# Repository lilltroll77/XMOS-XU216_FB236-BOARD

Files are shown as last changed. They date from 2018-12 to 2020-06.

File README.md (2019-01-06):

# XMOS-XU216_FB236-BOARD
### XMOS XU216-FB236 BOARD made in KiCad
**Current status: In DEVELOPMENT**

A 100 x 100 mm 4 layer PCB based on the XMOS XU216 FB236 chip. PCB can be cascaded during development with full JTAG support, and then be used as a galvanic isolated network without JTAG.\
[Schematic as pdf](https://github.com/lilltroll77/XMOS-XU216_FB236-BOARD/blob/master/XMOS_XUF216_FB236.pdf)

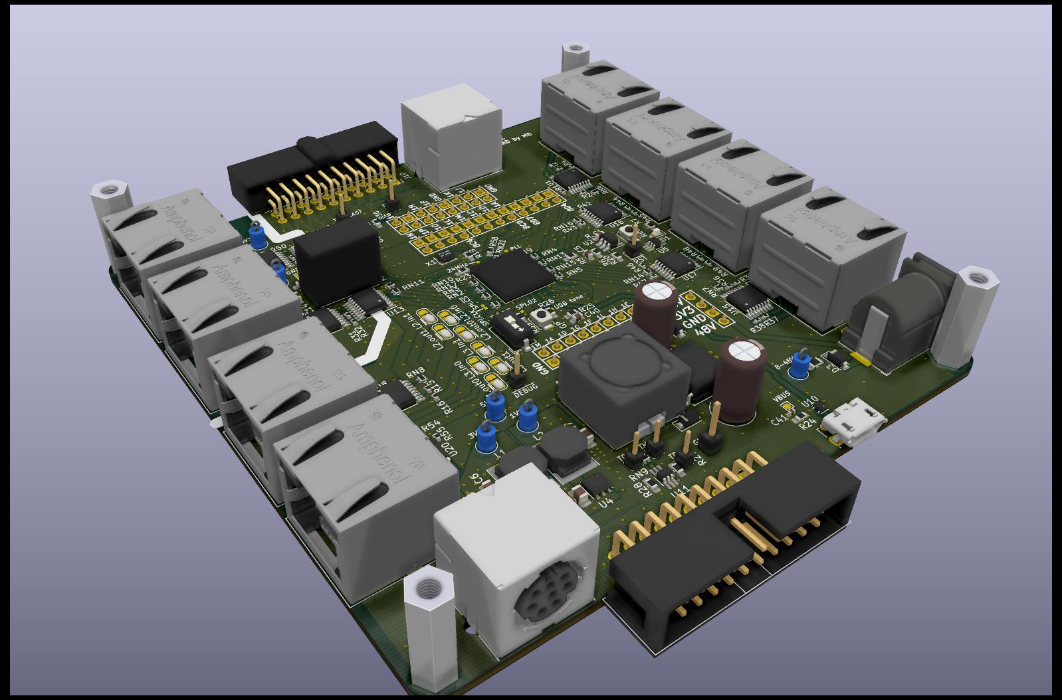
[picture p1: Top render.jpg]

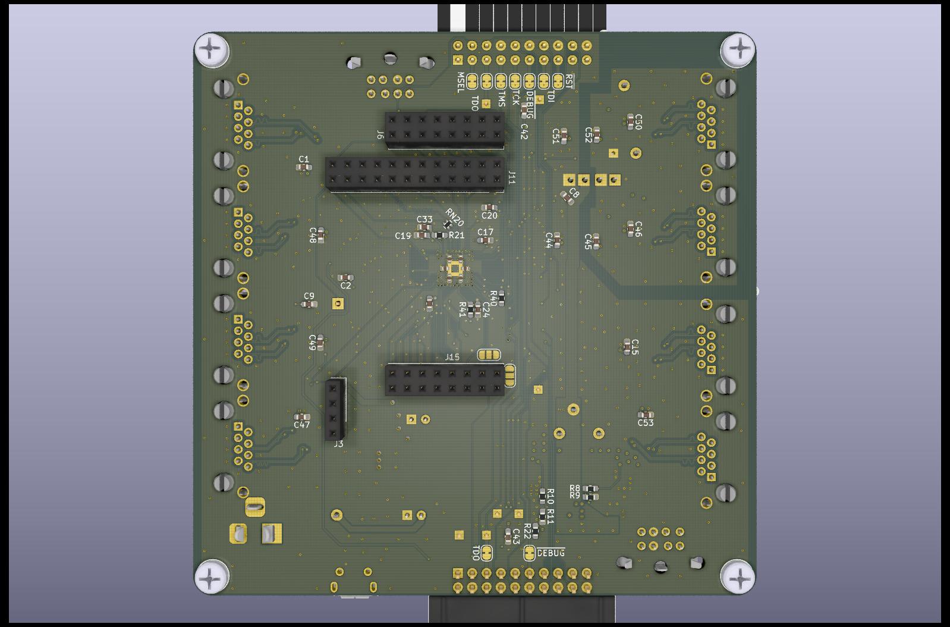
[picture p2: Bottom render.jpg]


The wrl file is a Virtual reality modeling language file of the board with components. 
It can be opened in [FreeCad](https://www.freecadweb.org/) with hardware acceleration. 
Software rendereing is not recommended for realtime view.
The parts for the PCB are stored in the shapes3D folder.

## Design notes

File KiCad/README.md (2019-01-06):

The library for the board should be included in the file XMOS_XUF216_FB236-cache.lib\
To view all 3D parts, you might need to add an alias in the KiCad "3D Search Path Configuration" window\
Alias = vrml\
Path = The path to the shapes3D folder on your local machine. (After you have cloned this project)

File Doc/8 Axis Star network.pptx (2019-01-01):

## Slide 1

Star network + JTAG line.
Compiler can create
the routing table for 1-9 PCBs.
Hub can be flashed, cards separated,
without any change to the code.
Isolation works when separated.

0

| JTAG | XL7
XL0 | XUF216 | XL6
XL1 | USB | XL5
| JTAG | XL4

| JTAG | XL7
XL0 | XUF216 | XL6
XL1 | USB | XL5
| JTAG | XL4

IDC

1

2

| JTAG | XL7
XL0 | XUF216 | XL6
XL1 | USB | XL5
| JTAG | XL4

IDC

COLOR = ACTIVATED

Tested with 9 PCBs in a star + XTAG line.
Full JTAG debug.
Realtime Stdout over UART.
Compiles and runs in the simulator.

3

| JTAG | XL7
XL0 | XUF216 | XL6
XL1 | USB | XL5
| JTAG | XL4

IDC

IDC

4

| JTAG | XL7
XL0 | XUF216 | XL6
XL1 | USB | XL5
| JTAG | XL4

5

| JTAG | XL7
XL0 | XUF216 | XL6
XL1 | USB | XL5
| JTAG | XL4

IDC

| JTAG | XL7
XL0 | XUF216 | XL6
XL1 | | XL5
| JTAG | XL4

IDC

6

PC

0

1

3

FLASH XL3 | JTAG | XL7
XL0 | XUF216 | XL6
XL1 | | XL5
USB XL2 | UART JTAG | XL4

XTAG UART

IDC

6

7 (not shown)

5

2

IDC

HUB

Boots over JTAG or from Flash

4

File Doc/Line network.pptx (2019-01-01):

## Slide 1

Simple line network. Compiler can
create the routing table for any length.
The Xlink bandwidth must be shared
between the boards.
Not suitable for robotics.

| XL3 JTAG | XL7
XL0 | XUF216 | XL6
XL1 | USB | XL5
| XL2 JTAG | XL4

COLOR = ACTIVATED

| XL3 JTAG | XL7
XL0 | XUF216 | XL6
XL1 | USB | XL5
| XL2 JTAG | XL4

IDC

Tested with 8 PCBs in a line + XTAG.
Full JTAG debug.
Compiles and runs in the simulator.

| XL3 JTAG | XL7
XL0 | XUF216 | XL6
XL1 | USB | XL5
| XL2 JTAG | XL4

IDC

| XL3 JTAG | XL7
XL0 | XUF216 | XL6
XL1 | | XL5
| XL2 JTAG | XL4

IDC

FLASH | XL3 JTAG | XL7
XL0 | XUF216 | XL6
XL1 | | XL5
USB | XL2 JTAG | XL4

XTAG

IDC

PC

IDC

Boots over JTAG or Flash

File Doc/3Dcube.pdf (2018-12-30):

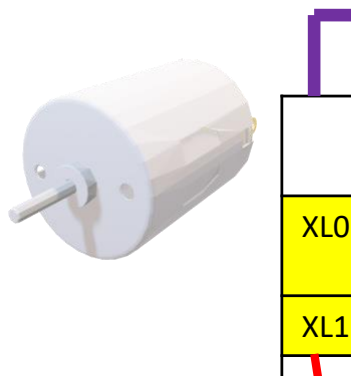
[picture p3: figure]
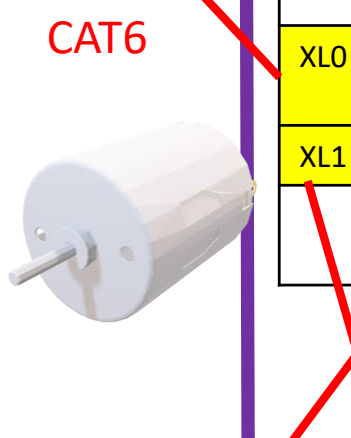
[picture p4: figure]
CAT6
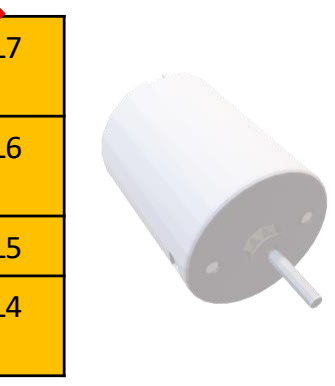
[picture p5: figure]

FLASH | XL3 JTAG | XL7
XL0 | XUF 216 IO | XL6

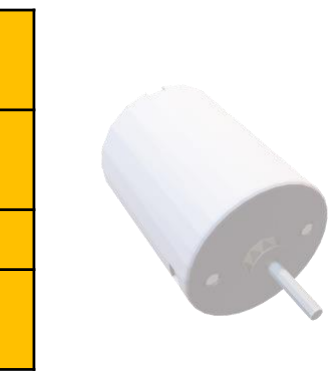
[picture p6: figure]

XL1 | | XL5
USB | XL2 JTAG | XL4

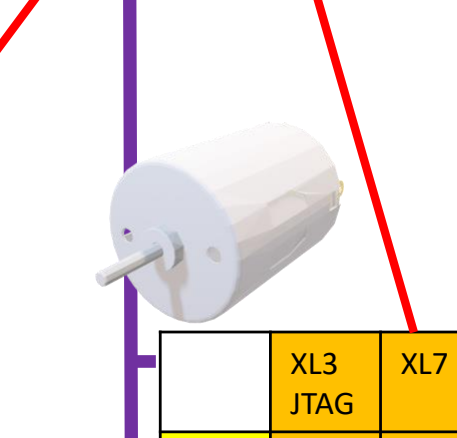
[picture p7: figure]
XL3 JTAG

XL0 | XUF 216 IO | XL6
XL1 | | XL5
| XL2 JTAG | XL4

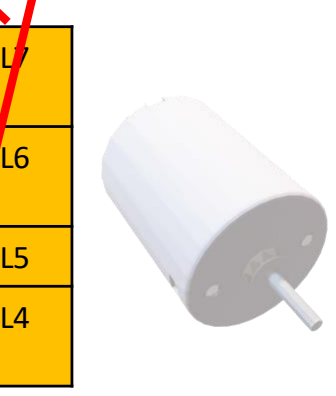
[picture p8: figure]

XL3
JTAG

XL7

XL0 | XUF
| 216 | XL6
XL1 | IO | XL5
| XL2 JTAG | XL4

## IDC

## IDC

## IDC

PC

## Isolated 3D cube network

## PSU

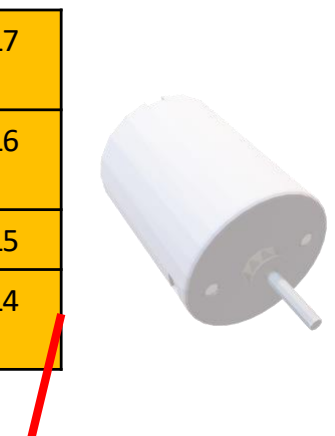
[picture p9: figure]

XL3 JTAG | XL7
XL0 | XUF 216 IO | XL6
XL1 | | XL5
| XL2 JTAG | XL4
| XL3 JTAG | XL7
XL0 | XUF 216 IO | XL6
XL1 | | XL5
| XL2 JTAG | XL4

## IDC

## IDC

XL3
JTAG

XL7

XL0 | XUF
| 216 | XL6
XL1 | IO | XL5
| XL2 JTAG | XL4
| XL3 JTAG | XL7
XL0 | XUF 216 IO | XL6
XL1 | | XL5
| XL2 JTAG | XL4

## IDC

## IDC

| XL3 JTAG | XL7
XL0 | XUF 216 IO | XL6
XL1 | | XL5
| XL2 JTAG | XL4

## IDC

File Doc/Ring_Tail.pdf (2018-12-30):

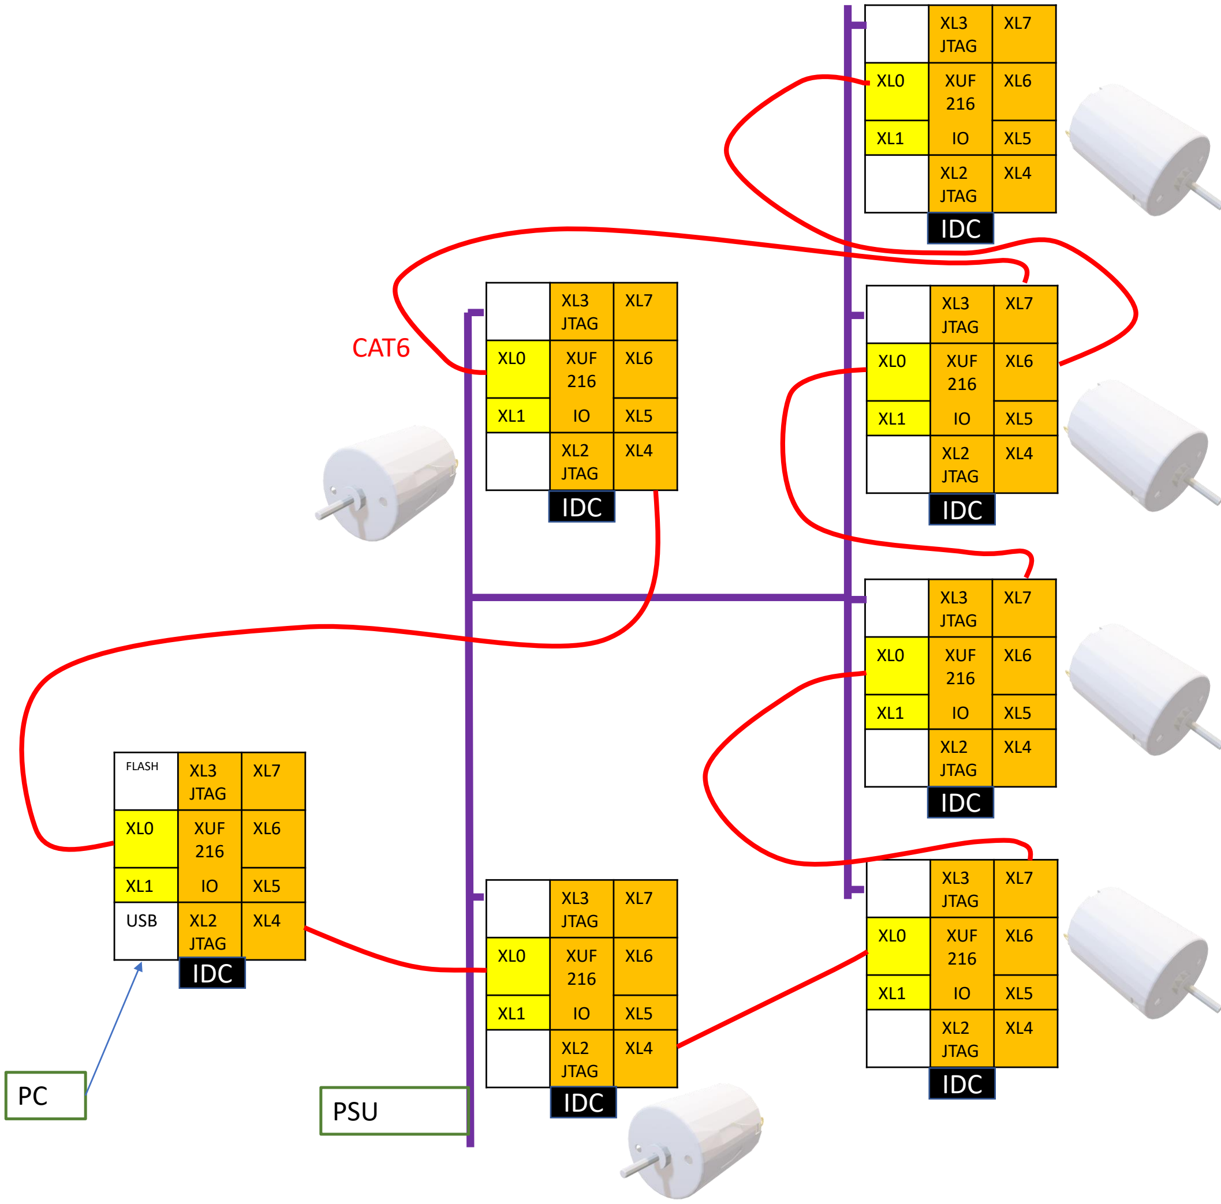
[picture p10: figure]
FLASH; XL3 JTAG; XUF 216 IO; USB; XL2 JTAG; XUF; IDC; CAT6; PSU

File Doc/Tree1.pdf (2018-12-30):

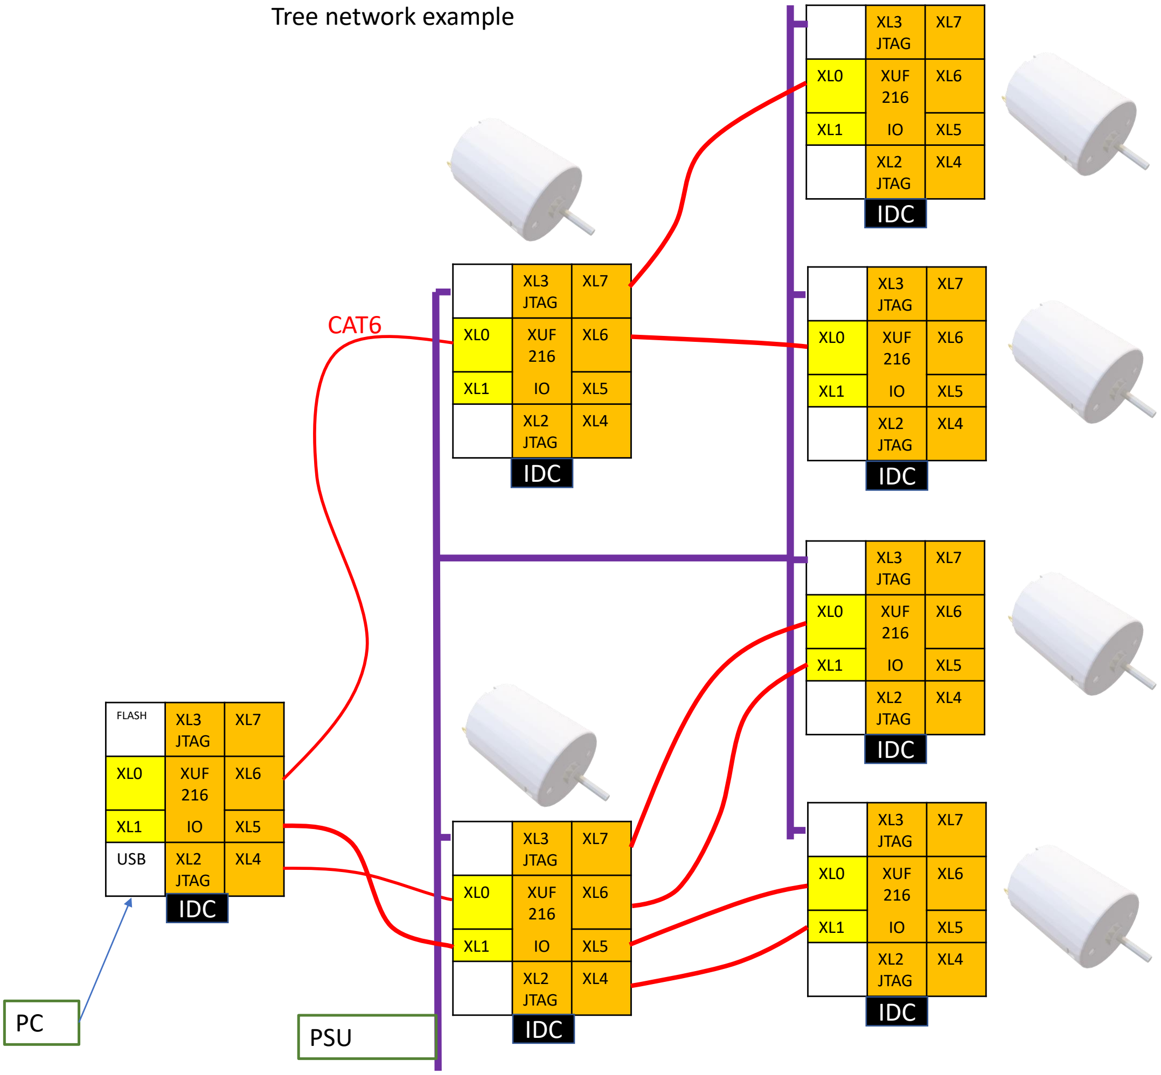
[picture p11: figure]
FLASH; XL3 JTAG; XUF 216 IO; USB; XL2 JTAG; XUF; IDC; CAT6; PSU; Tree network example

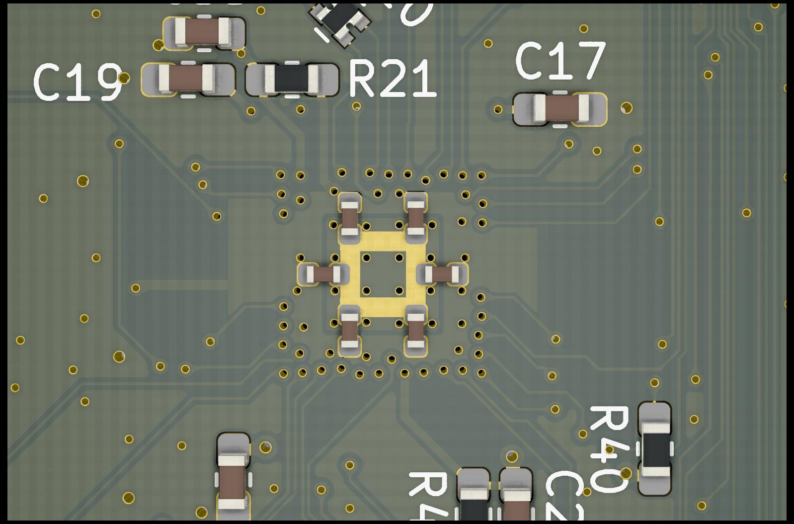
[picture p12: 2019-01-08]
1V0 0402Caps.jpg

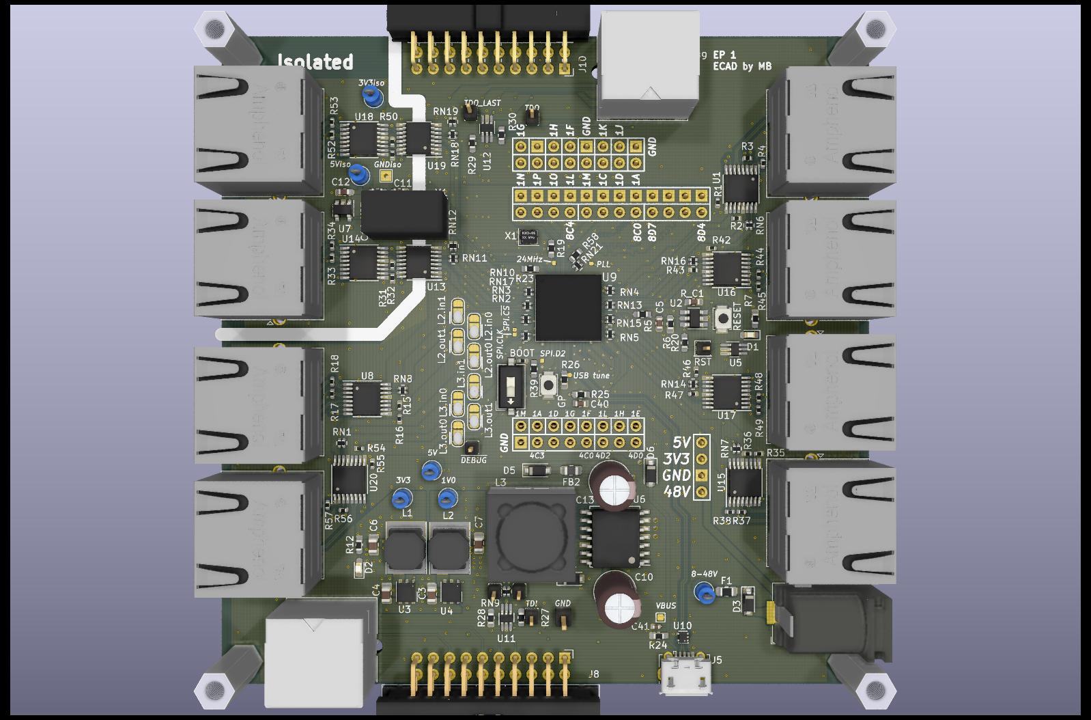
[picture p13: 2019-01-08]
Top render2.jpg

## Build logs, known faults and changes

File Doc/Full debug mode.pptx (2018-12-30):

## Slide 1

Advanced debugging during development

| XL3 JTAG | XL7
XL0 | XUF216 | XL6
XL1 | USB | XL5
| XL2 JTAG | XL4

| XL3 JTAG | XL7
XL0 | XUF216 | XL6
XL1 | USB | XL5
| XL2 JTAG | XL4

IDC

| XL3 JTAG | XL7
XL0 | XUF216 | XL6
XL1 | USB | XL5
| XL2 JTAG | XL4

IDC

| XL3 JTAG | XL7
XL0 | XUF216 | XL6
XL1 | USB | XL5
| XL2 JTAG | XL4

FLASH | XL3 JTAG | XL7
XL0 | XUF216 | XL6
XL1 | | XL5
USB | XL2 JTAG | XL4

XTAG

IDC

IDC

PC

IDC

Boots over JTAG

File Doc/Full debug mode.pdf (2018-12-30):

# XTAG

FLASH | XL3 JTAG | XL7
XL0 | XUF 216 | XL6
XL1 | | XL5
USB | XL2 JTAG | XL4
| XL3 JTAG | XL7
XL0 | XUF 216 USB | XL6
XL1 | | XL5
| XL2 JTAG | XL4
| XL3 JTAG | XL7
XL0 | XUF 216 USB | XL6
XL1 | | XL5
| XL2 JTAG | XL4
| XL3 JTAG | XL7
XL0 | XUF 216 USB | XL6
XL1 | | XL5
| XL2 JTAG | XL4
| XL3 JTAG | XL7
XL0 | XUF 216 USB | XL6
XL1 | | XL5
| XL2 JTAG | XL4

## IDC

## IDC

## IDC

## IDC

## IDC

PC

## Advanced debugging during development

## Boots over JTAG

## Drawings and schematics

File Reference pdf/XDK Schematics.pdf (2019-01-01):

## UART_TXD UART_RXD

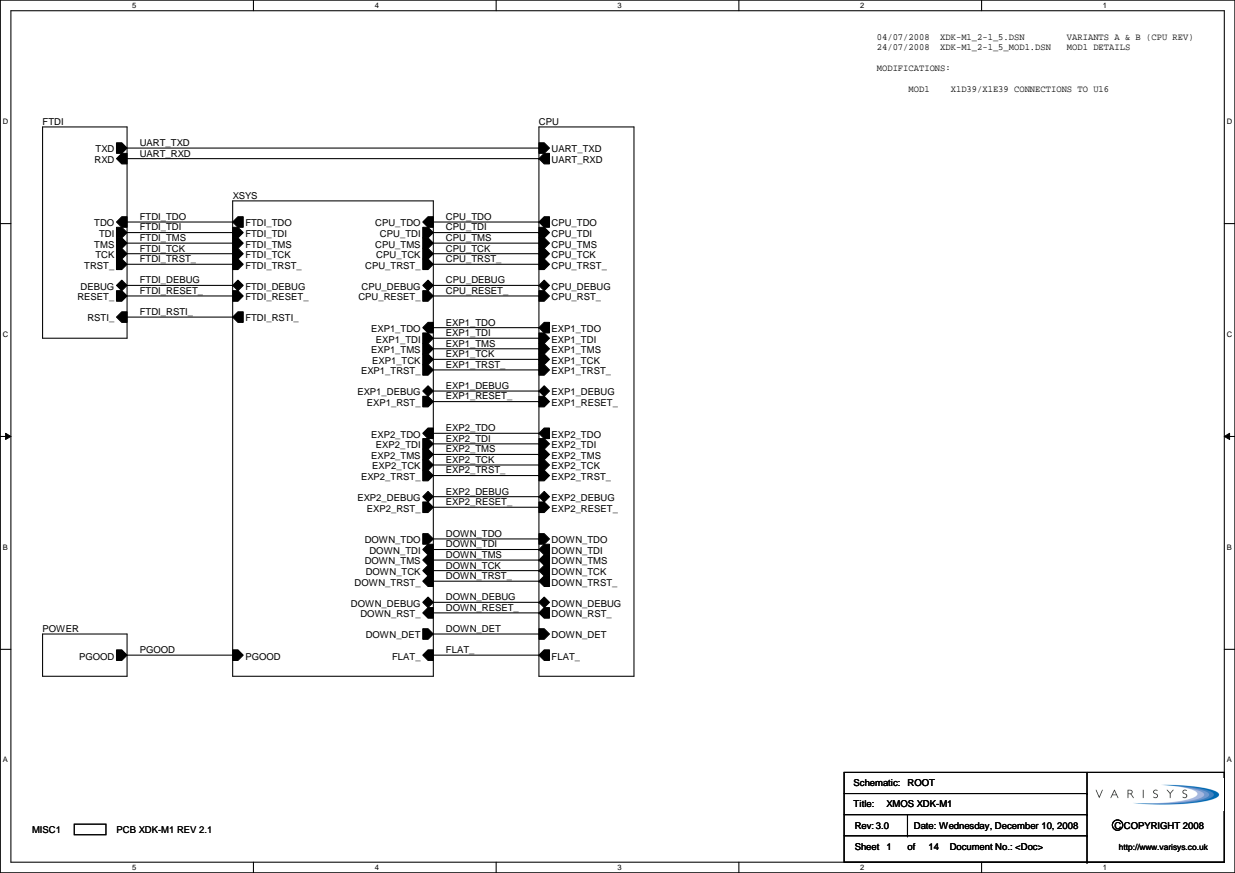
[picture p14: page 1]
CPU_TDO CPU_TDI; DOWN_DET; FLAT_; EXP1_TCK EXP1_TRST_; EXP1_TMS; EXP1_DEBUG EXP1_RESET_; EXP1_TDI; EXP2_TDO; EXP2_TCK EXP2_TRST_; EXP2_TMS; EXP2_DEBUG EXP2_RESET_; EXP2_TDI; DOWN_TDO; DOWN_TCK DOWN_TRST_; DOWN_TMS; DOWN_DEBUG DOWN_RESET_; DOWN_TDI; FTDI_TDO FTDI_TDI; PGOOD; Title:; Document No.:; Rev:; Date:; Sheet; C COPYRIGHT 2008; Schematic:; <Doc>; http://www.varisys.co.uk; XMOS XDK-M1; Wednesday, December 10, 2008; ROOT; 04/07/2008 XDK-M1_2-1_5.DSN; VARIANTS A & B (CPU REV); MOD1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

FTDI_TMS | CPU_TMS
FTDI_TCK | CPU_TCK
FTDI_TRST_ | CPU_TRST_

FTDI_DEBUG | CPU_DEBUG
FTDI_RESET_ | CPU_RESET_

FTDI_RSTI_ | EXP1_TDO

## SPARE

SPARE M22 | SPARE | AD16 SPARE | AD14 SPARE | AD13 SPARE | AD12 SPARE | AD11 SPARE | AD9 SPARE | AC22 SPARE | AC14 SPARE | AC13 SPARE | AC12 SPARE | AC11 SPARE | AC3 SPARE | AB24 SPARE | AB16 SPARE | AB15 SPARE | AB13 SPARE | AB12 SPARE | AB10 SPARE | AB9 SPARE | AB1 SPARE | AA15 SPARE | AA14 SPARE | AA13 SPARE | AA12 SPARE | AA11 SPARE | AA10 SPARE | T23 SPARE | T2 SPARE | P22 SPARE | P2 SPARE | P1 SPARE | N22 SPARE | N21 SPARE | N4 SPARE | N3 SPARE | N2 SPARE | N1

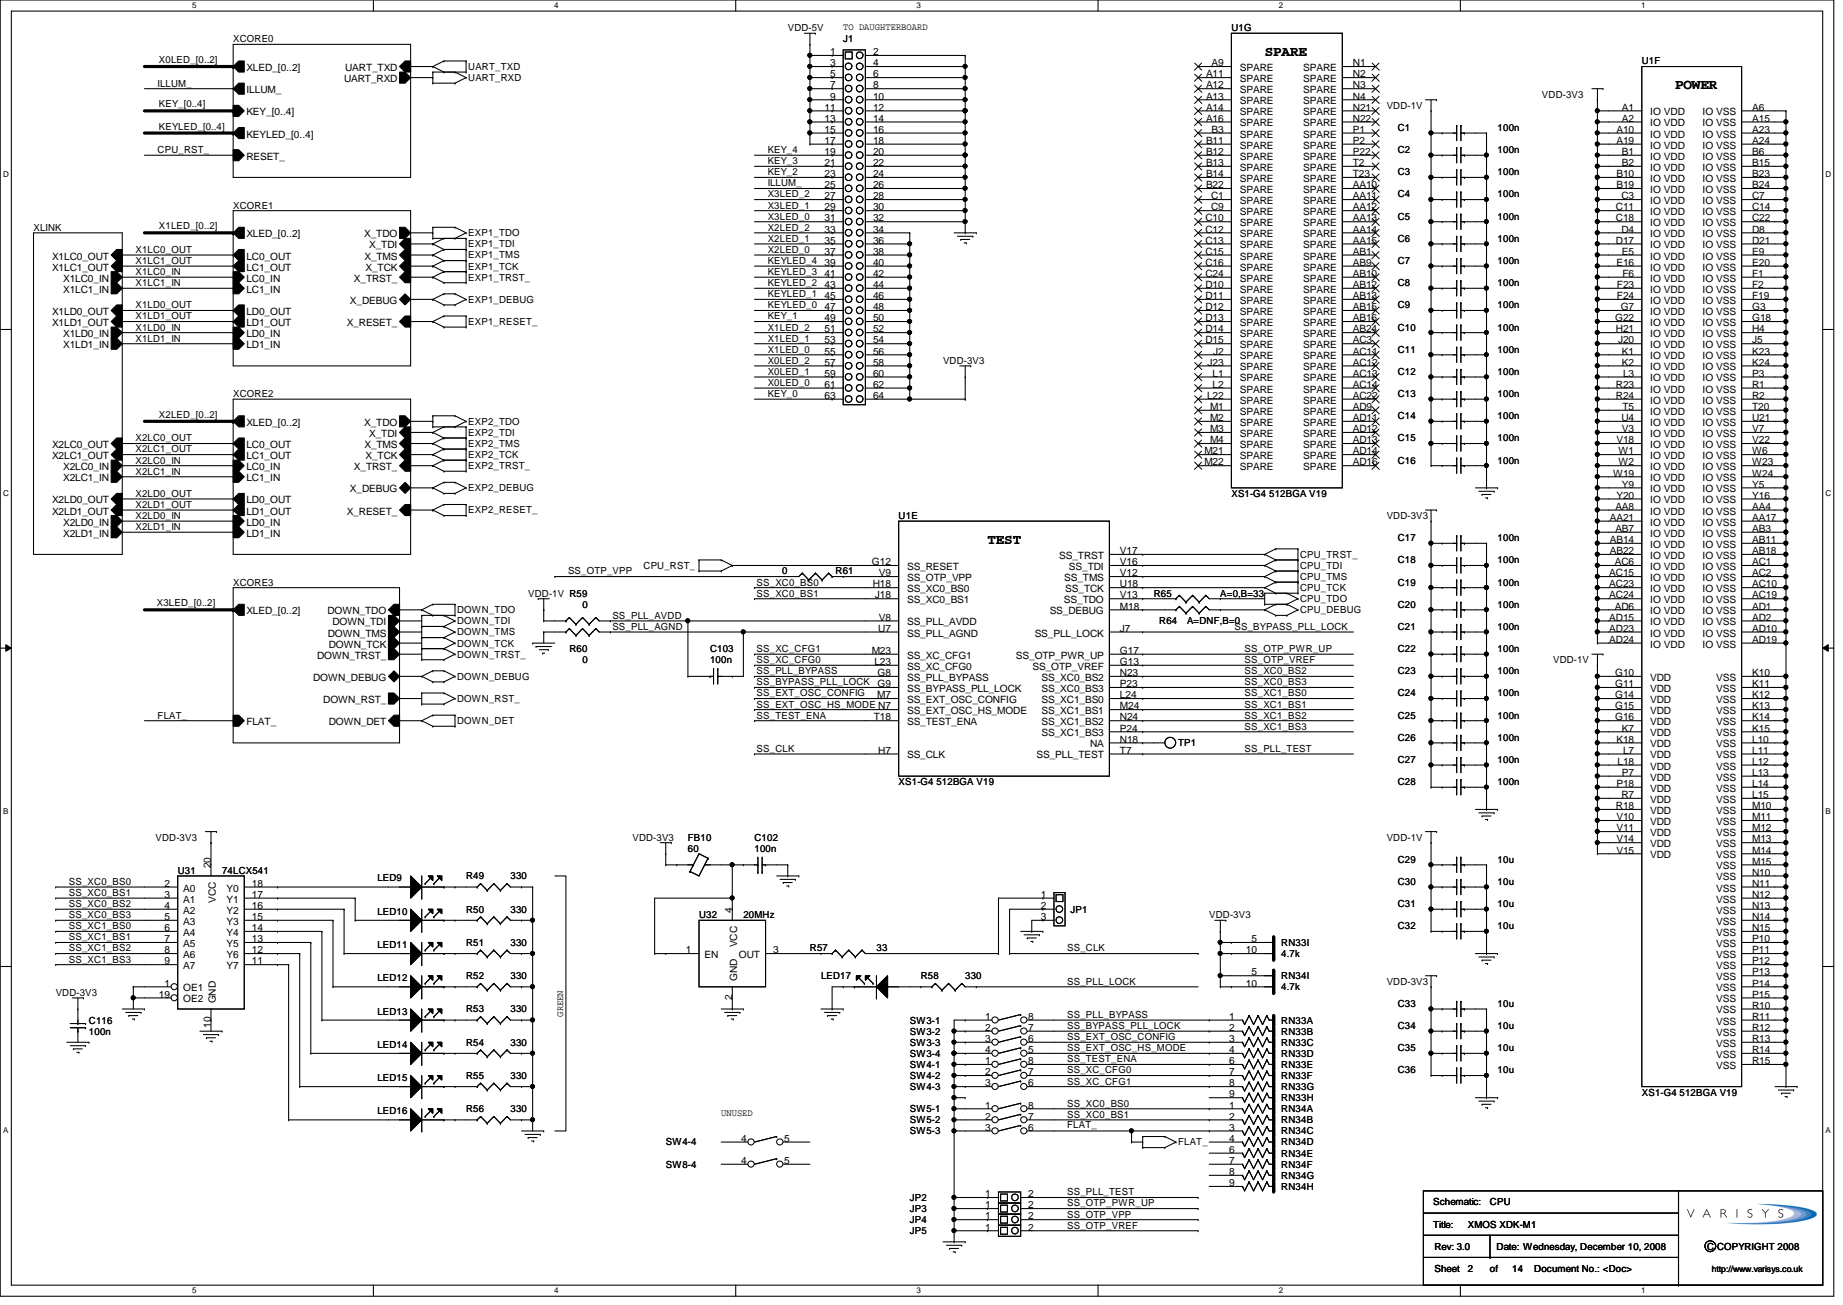
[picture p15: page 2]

## TDI

## TMS

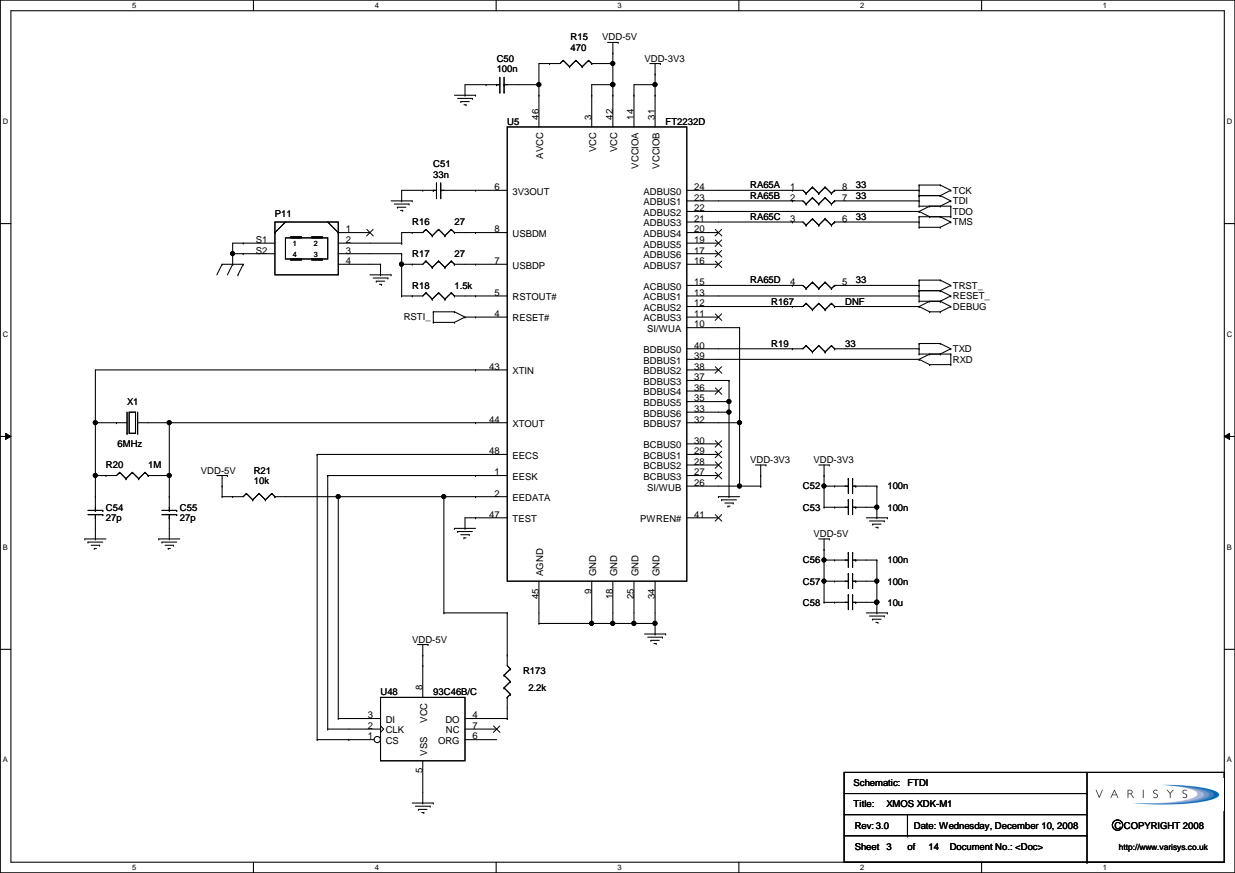
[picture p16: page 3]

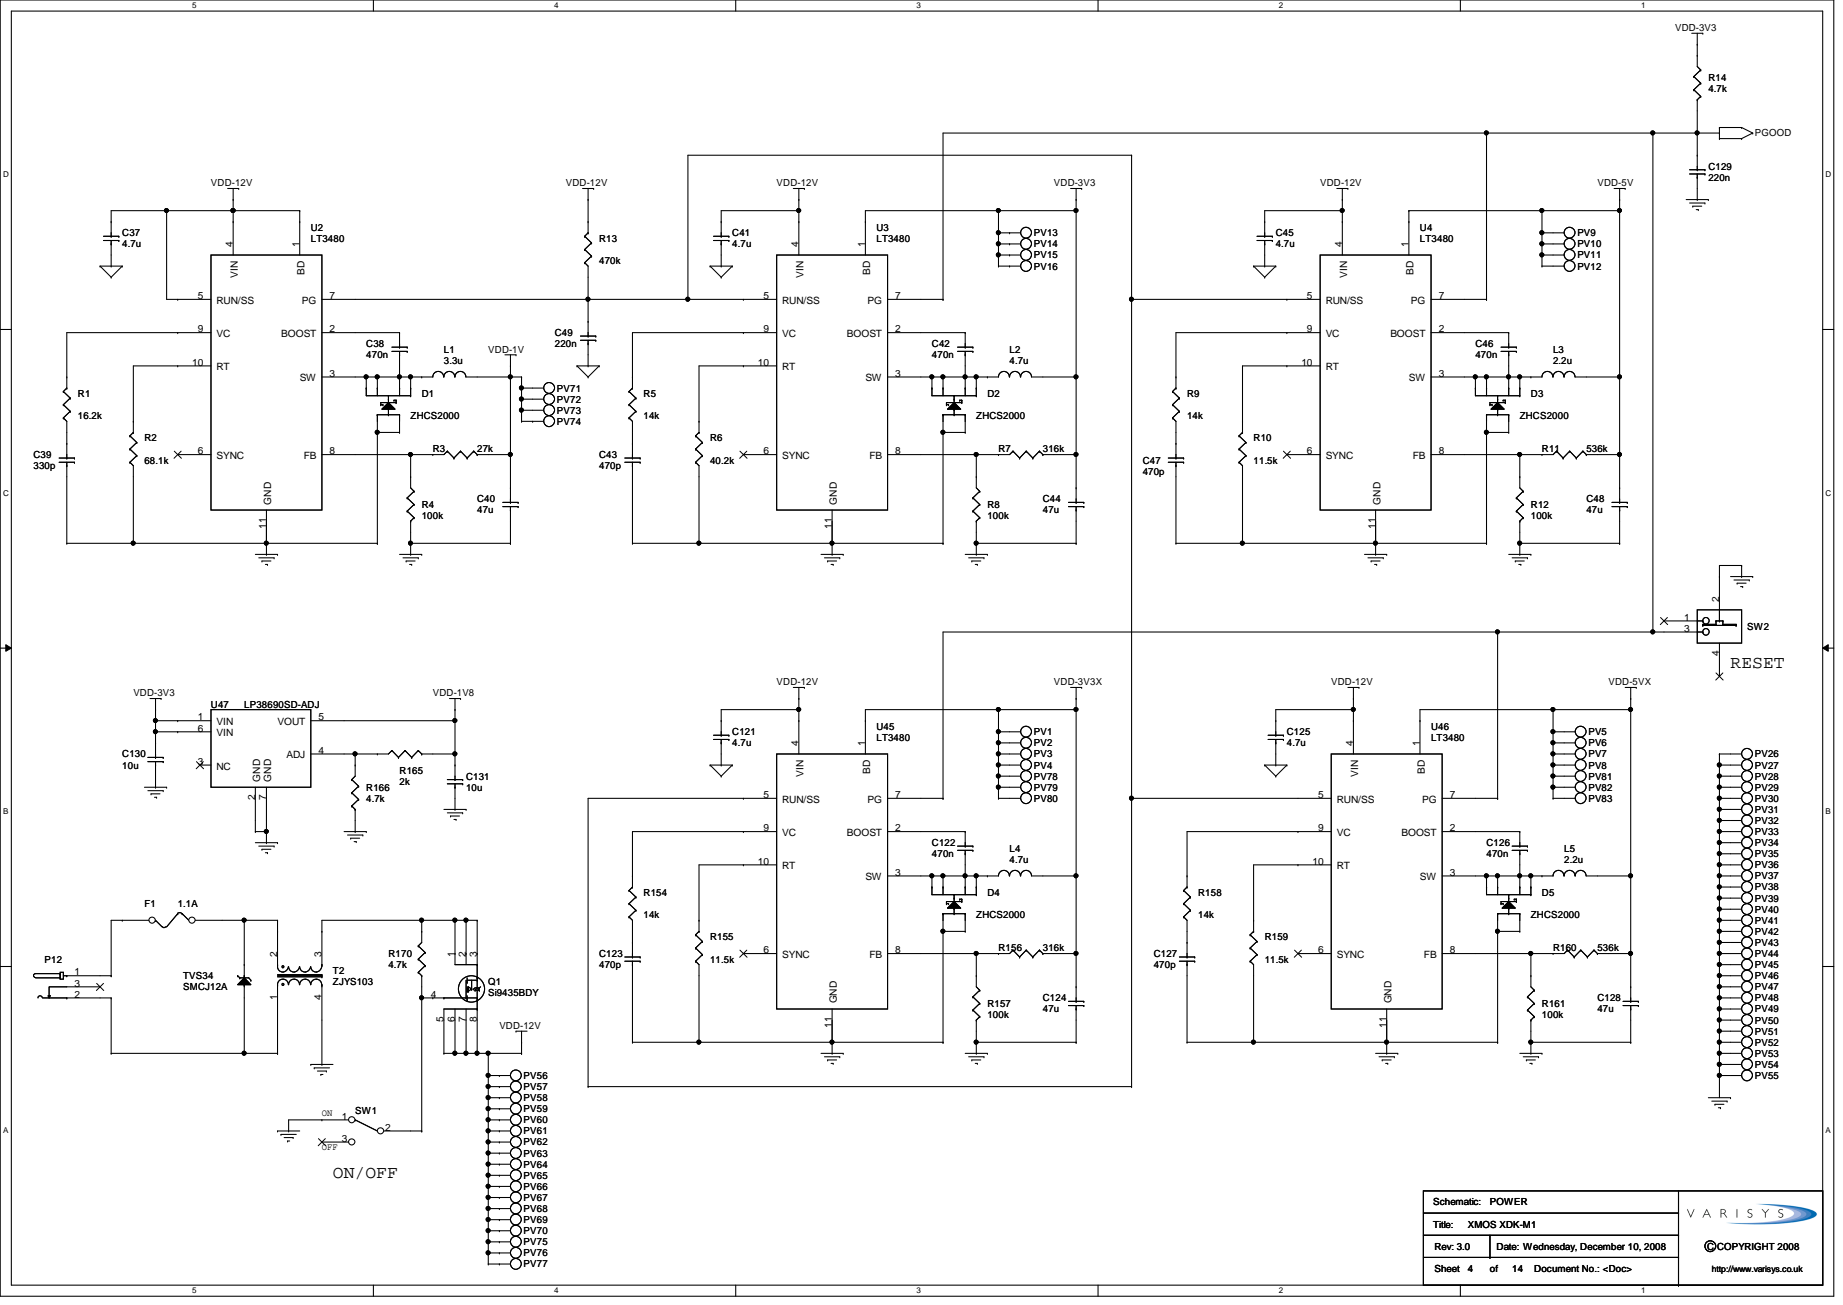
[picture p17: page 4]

## SRAM_OE_

## SRAM_WE_

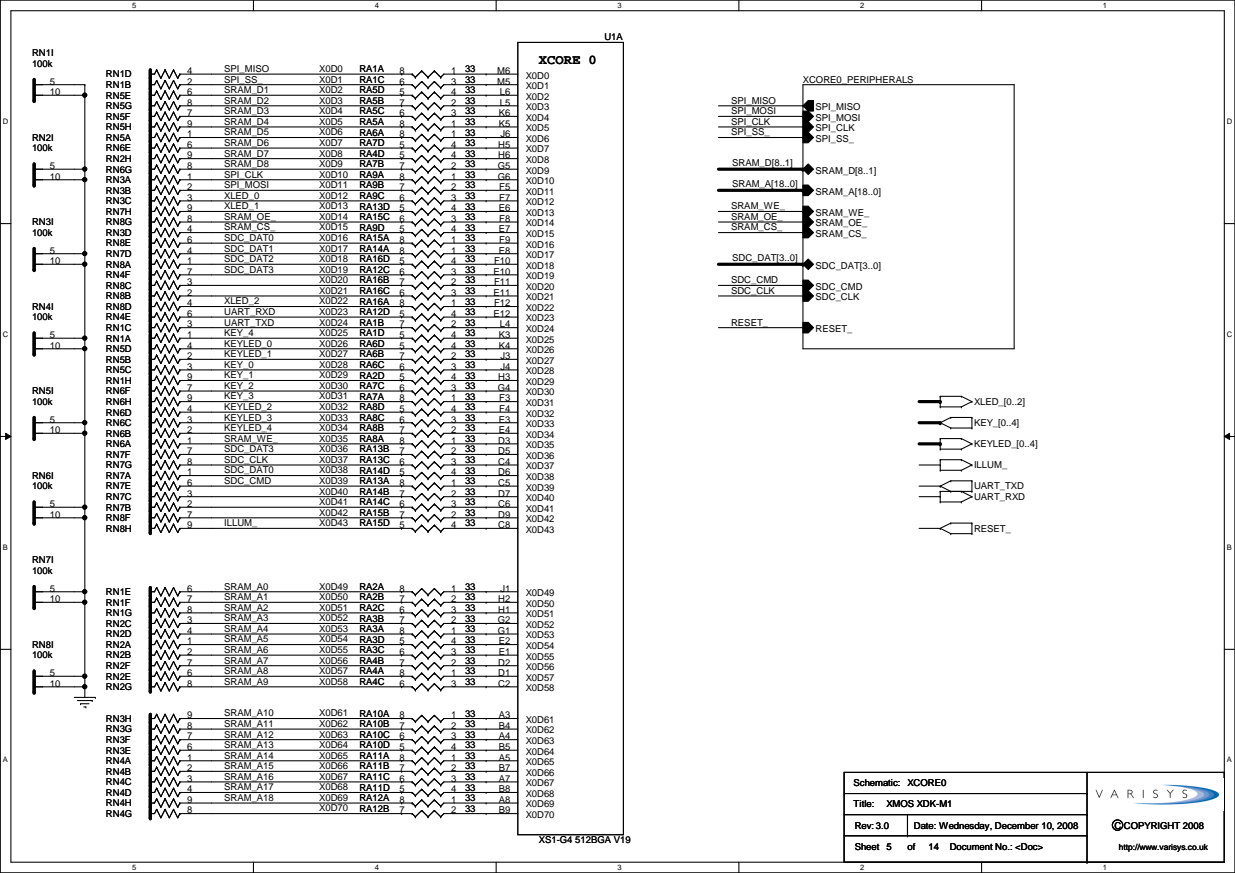
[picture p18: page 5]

## SPI_CLK

## SPI_SS_

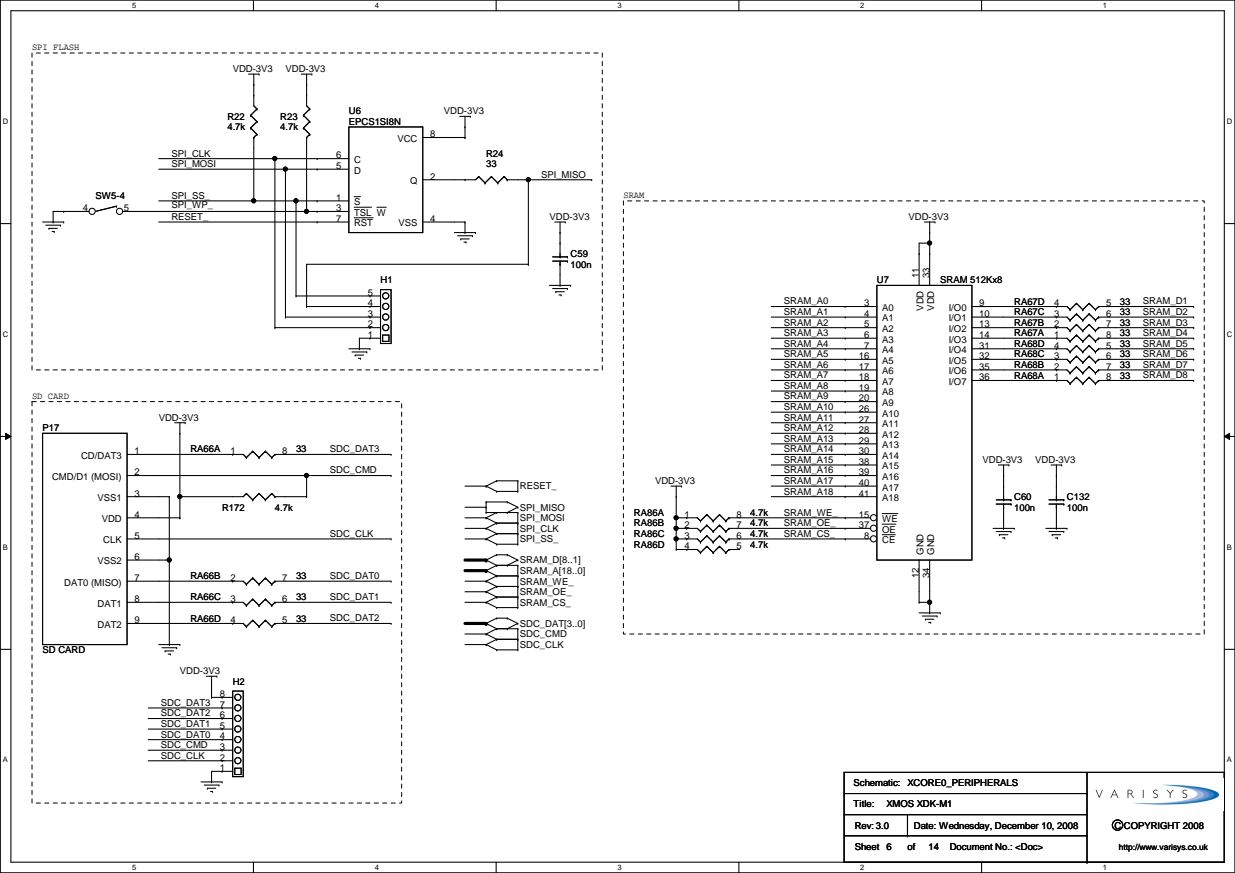
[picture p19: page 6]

## XCORE 1

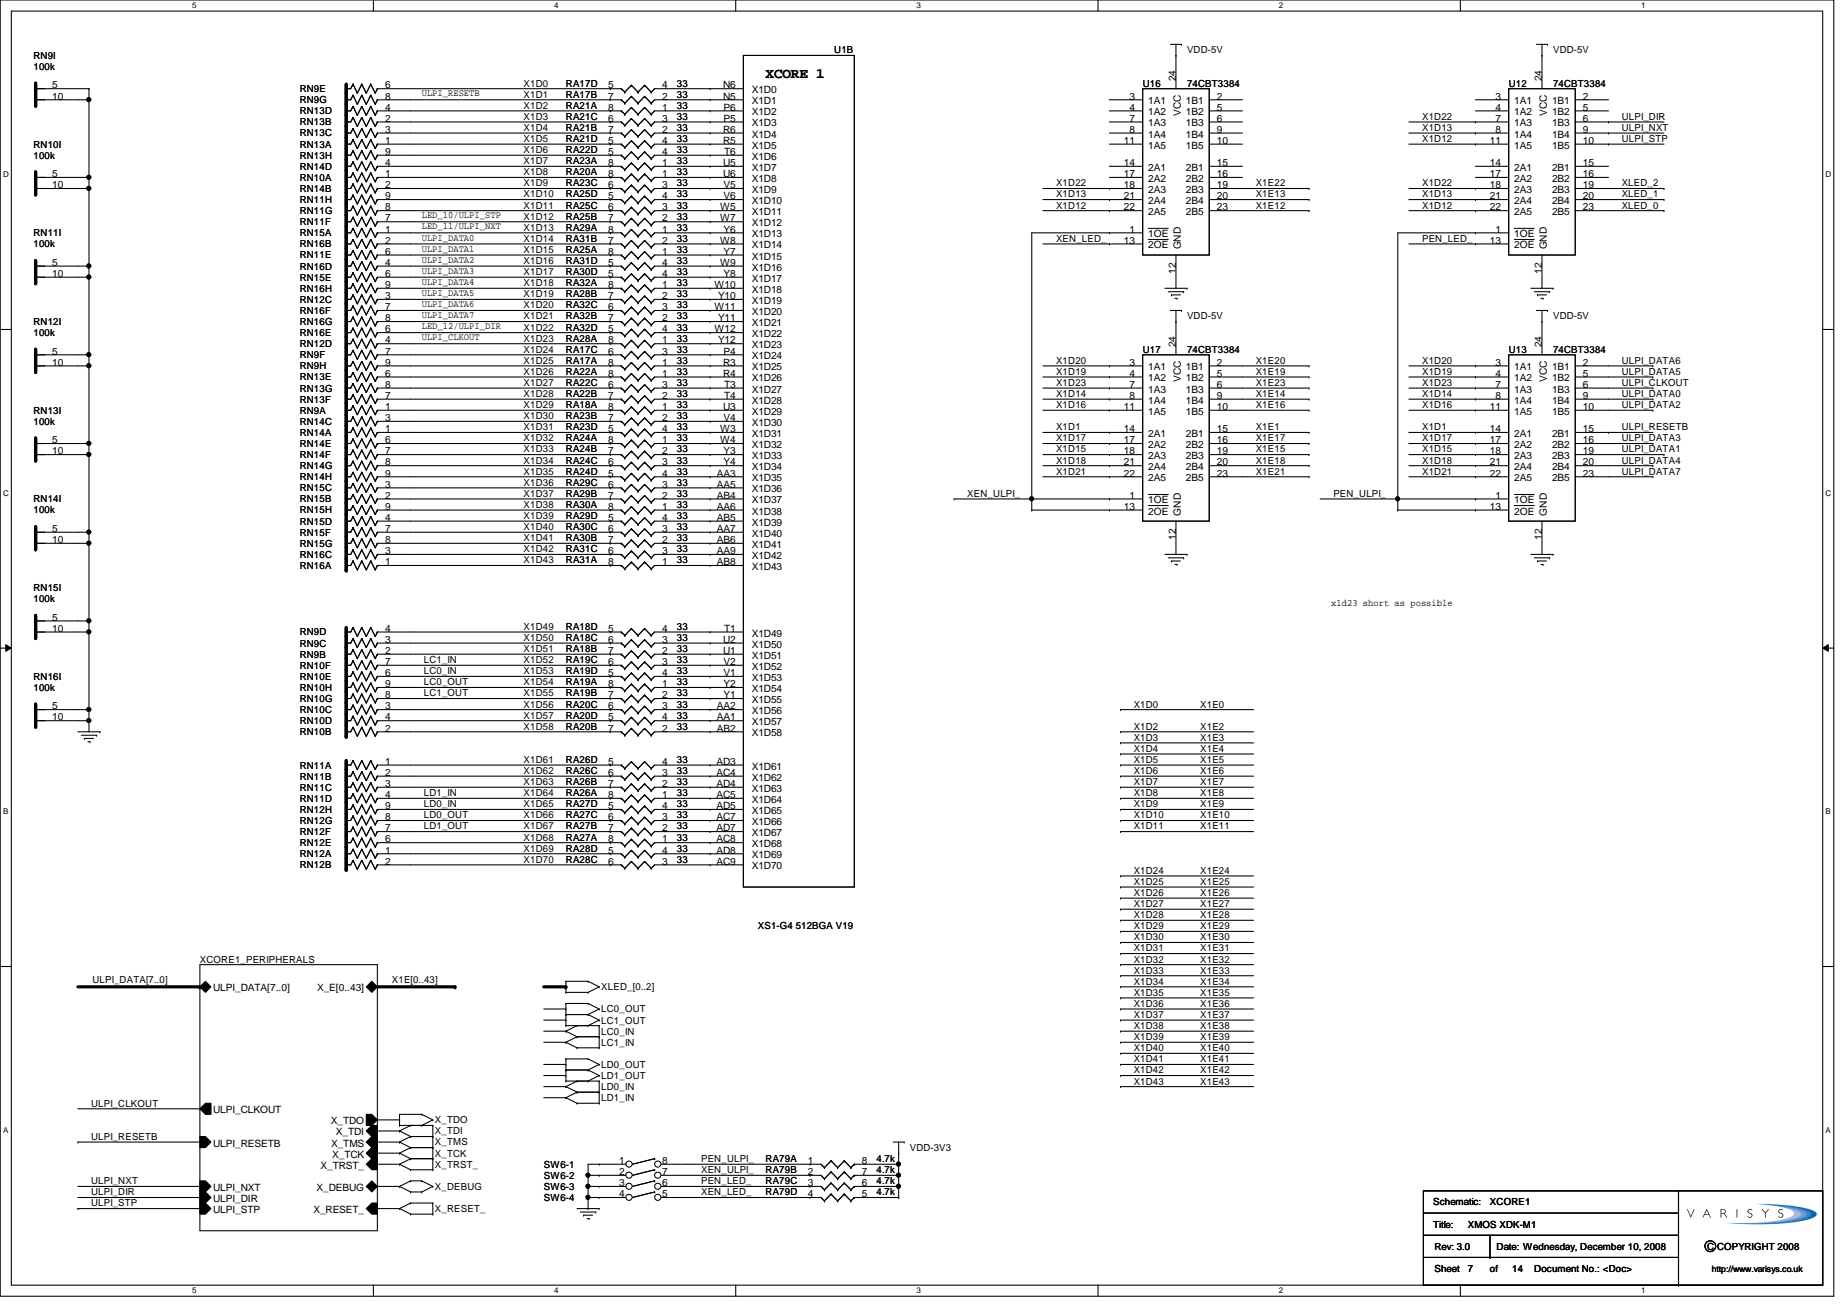
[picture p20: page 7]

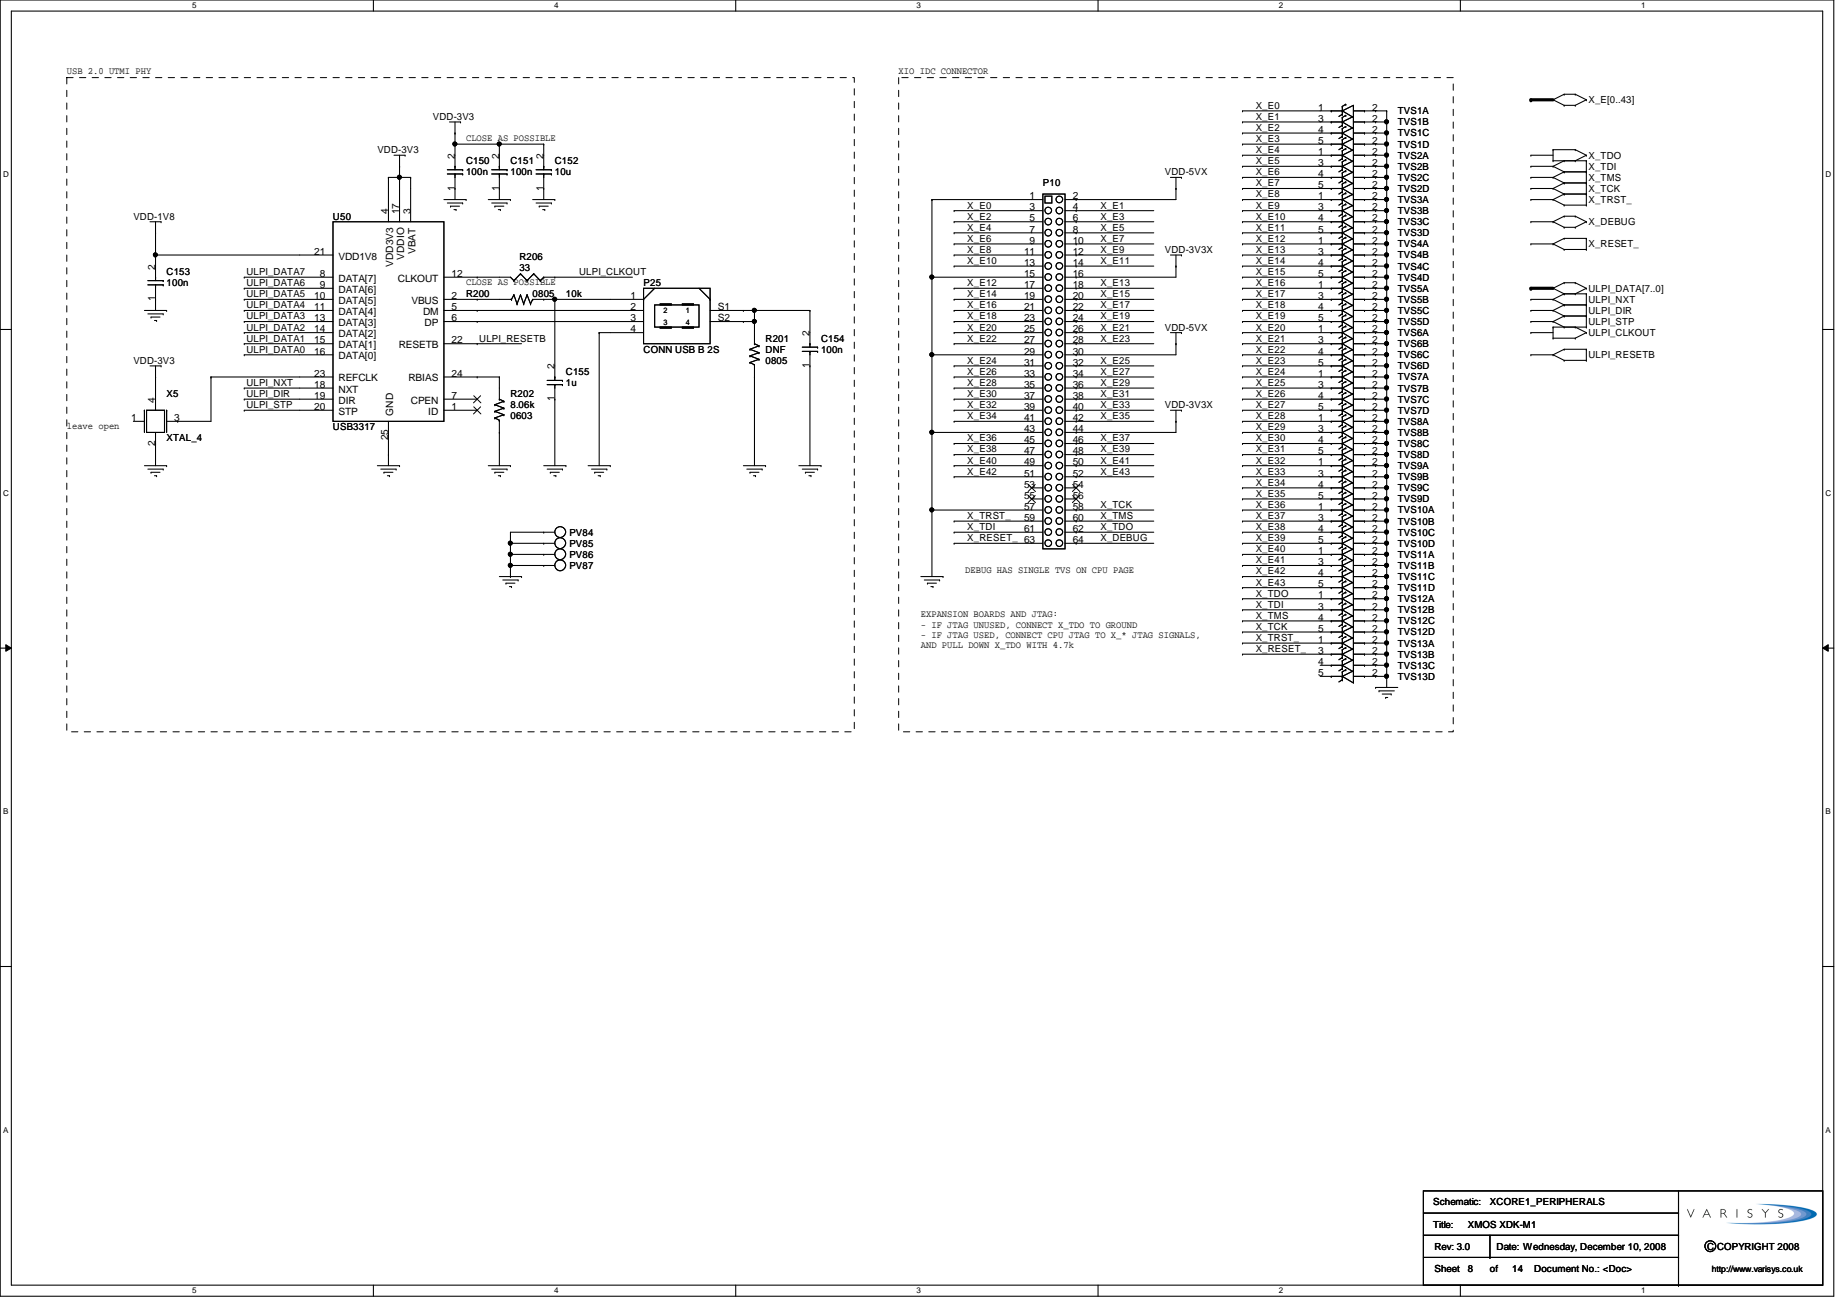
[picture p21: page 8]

DEBUG HAS SINGLE TVS ON CPU PAGE

EXPANSION BOARDS AND JTAG:
- IF JTAG UNUSED, CONNECT X_TDO TO GROUND
- IF JTAG USED, CONNECT CPU JTAG TO X_* JTAG SIGNALS,
AND PULL DOWN X_TDO WITH 4.7k

## XCORE 2

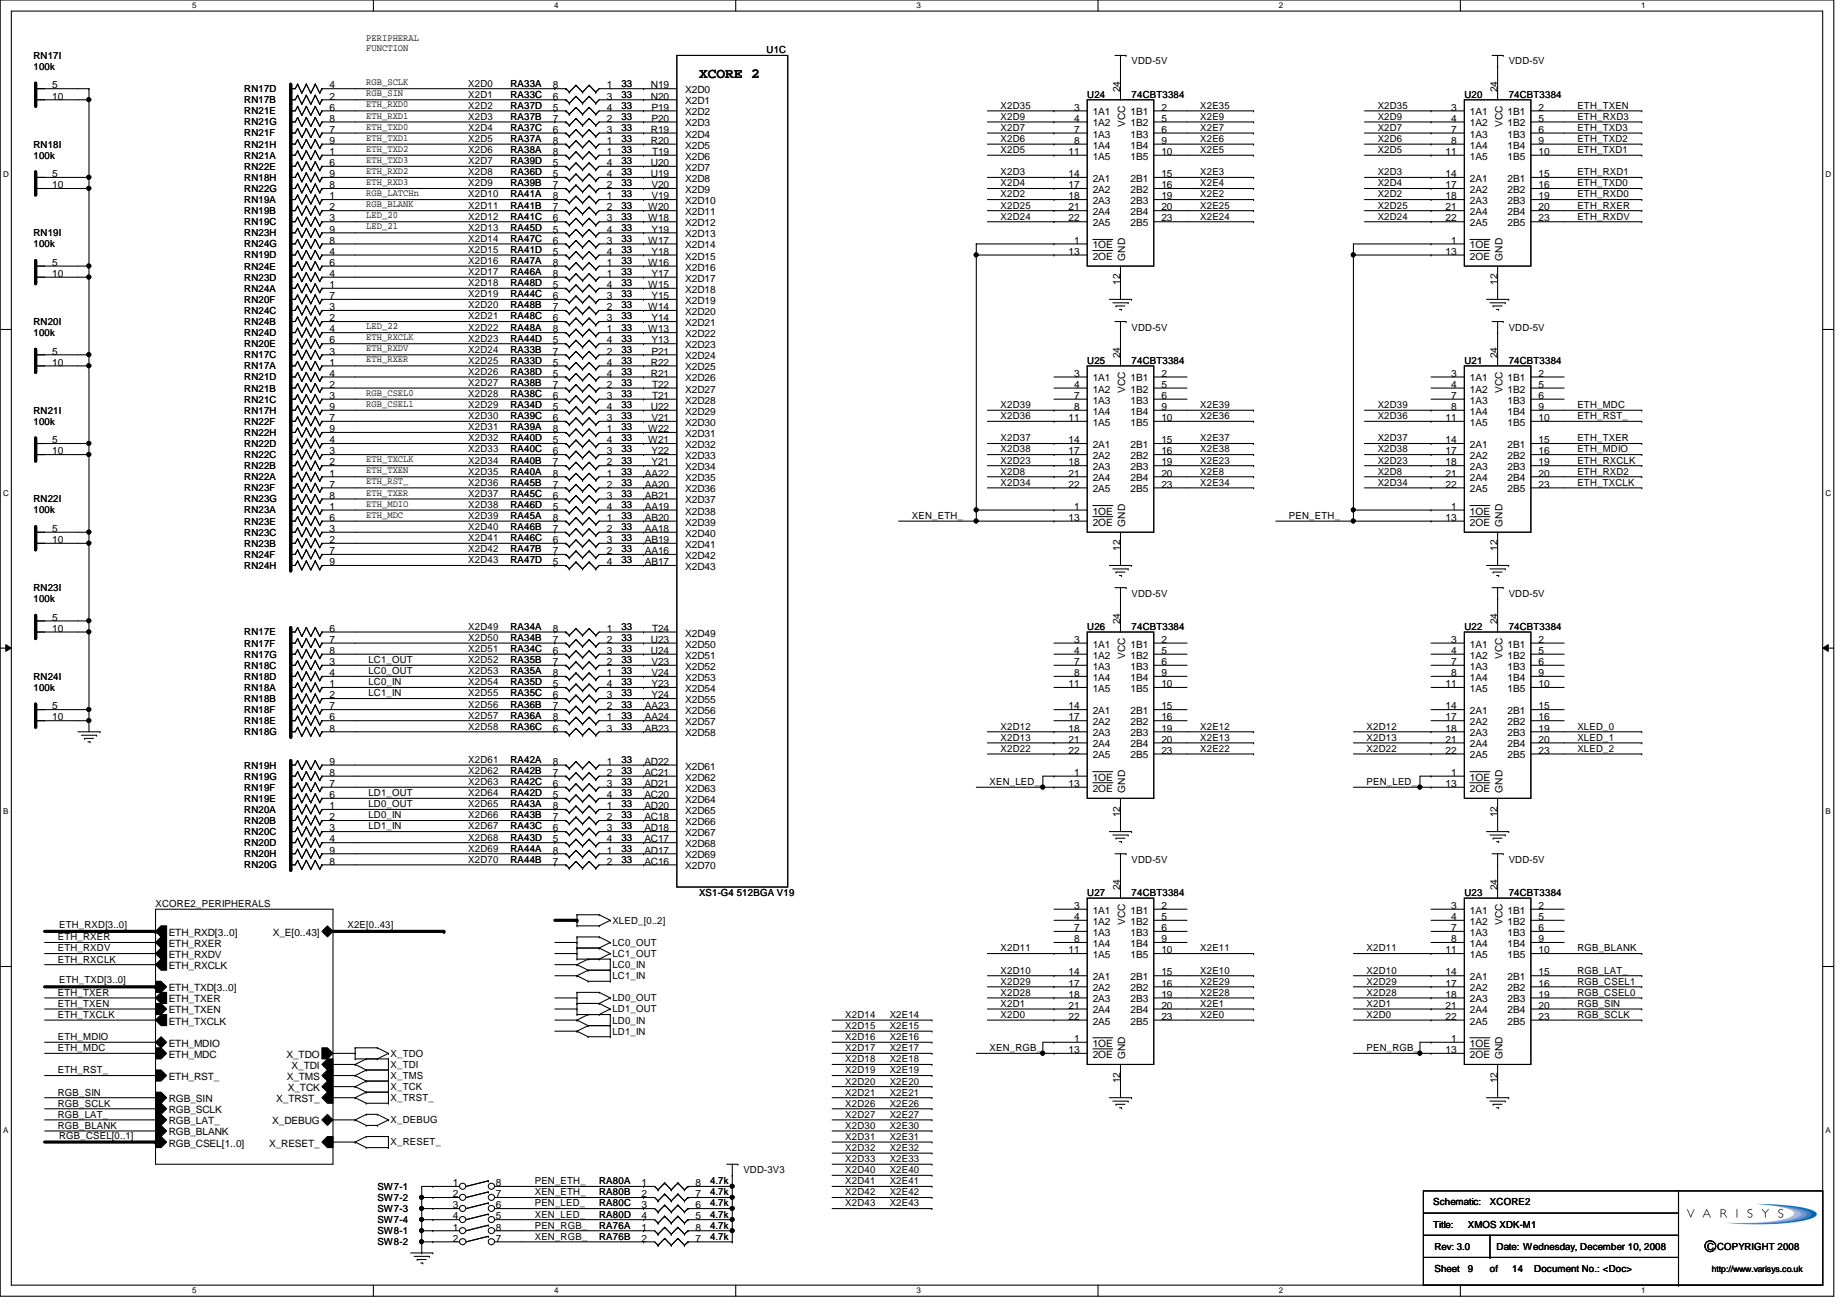
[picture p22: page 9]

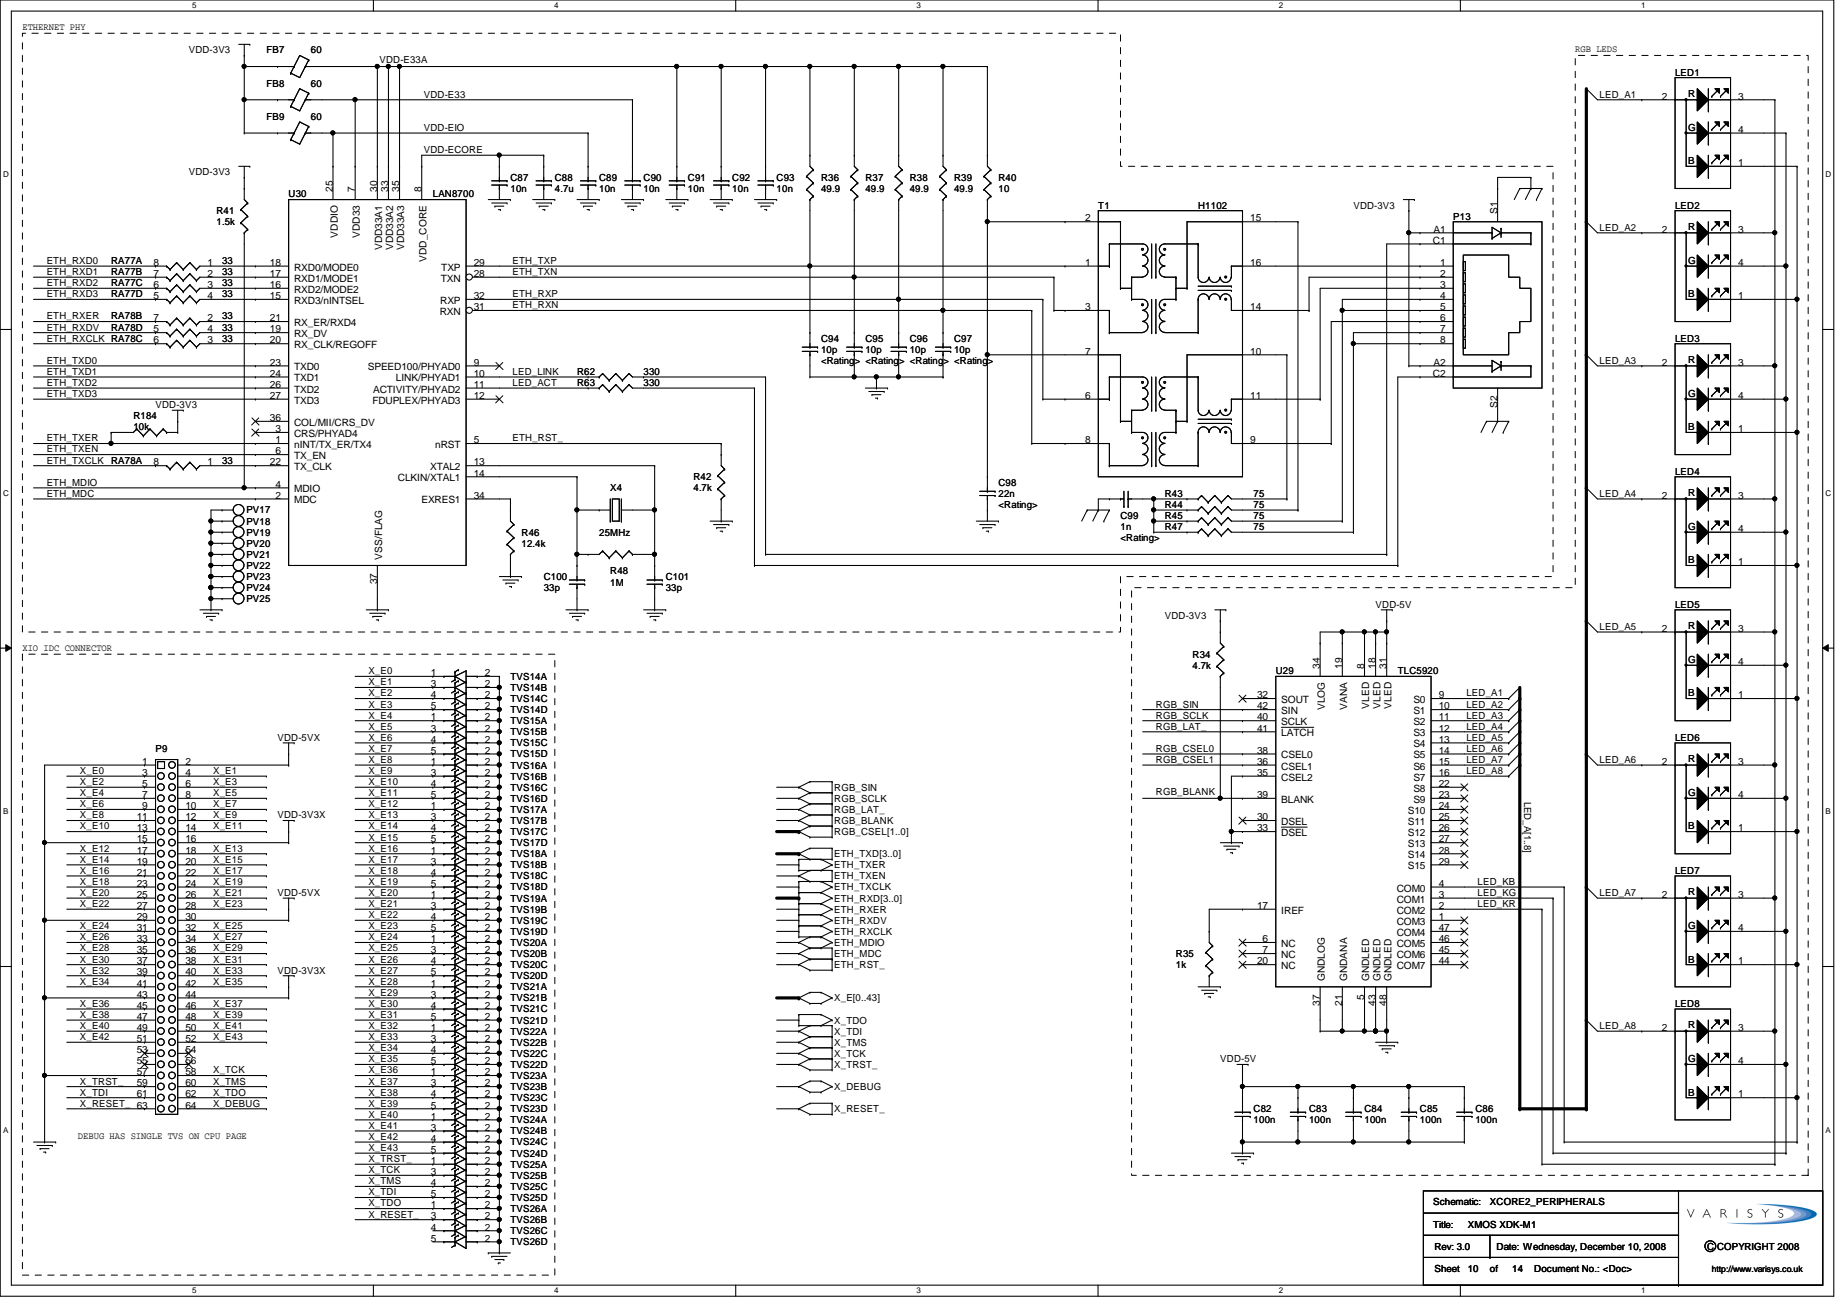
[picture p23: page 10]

DEBUG HAS SINGLE TVS ON CPU PAGE

## LCD_R[5..0]

## LCD_G[5..0]

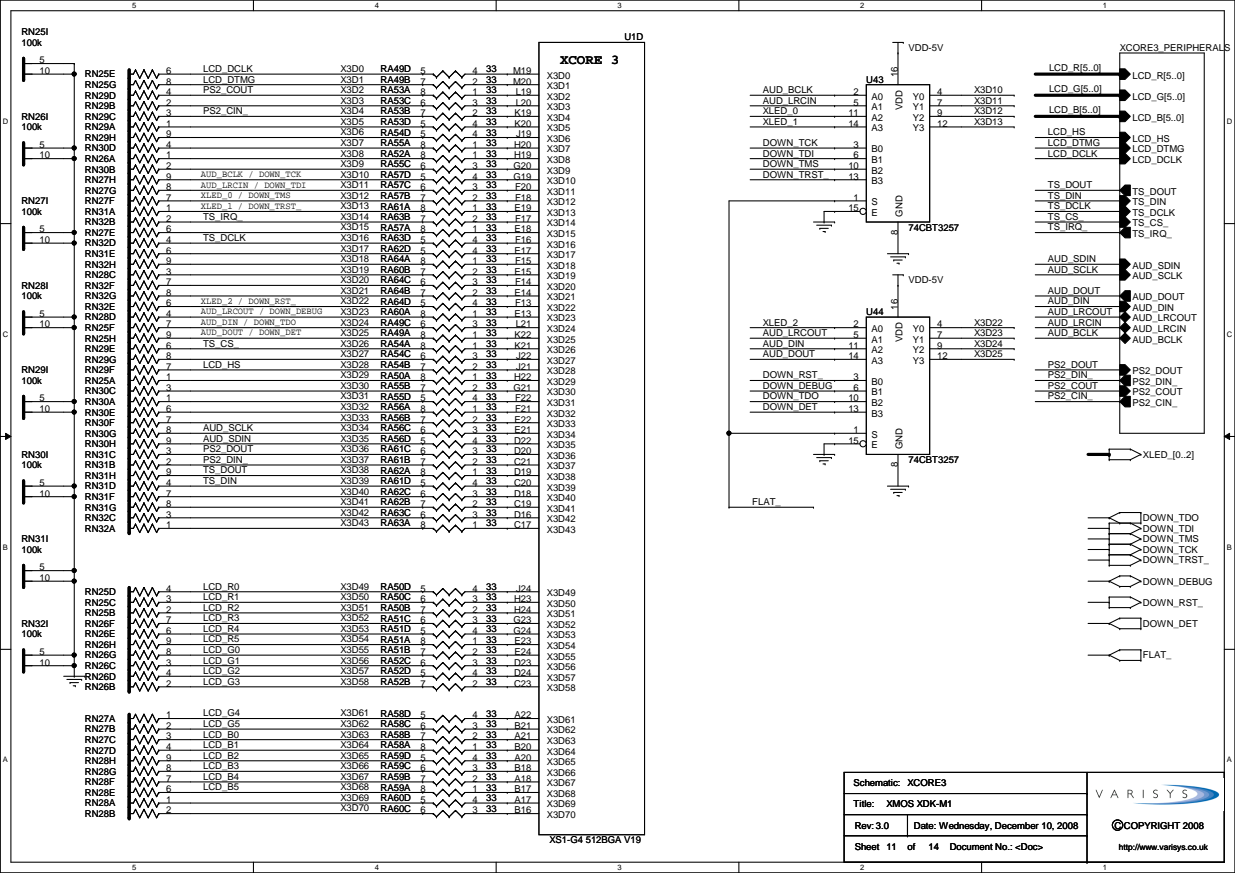
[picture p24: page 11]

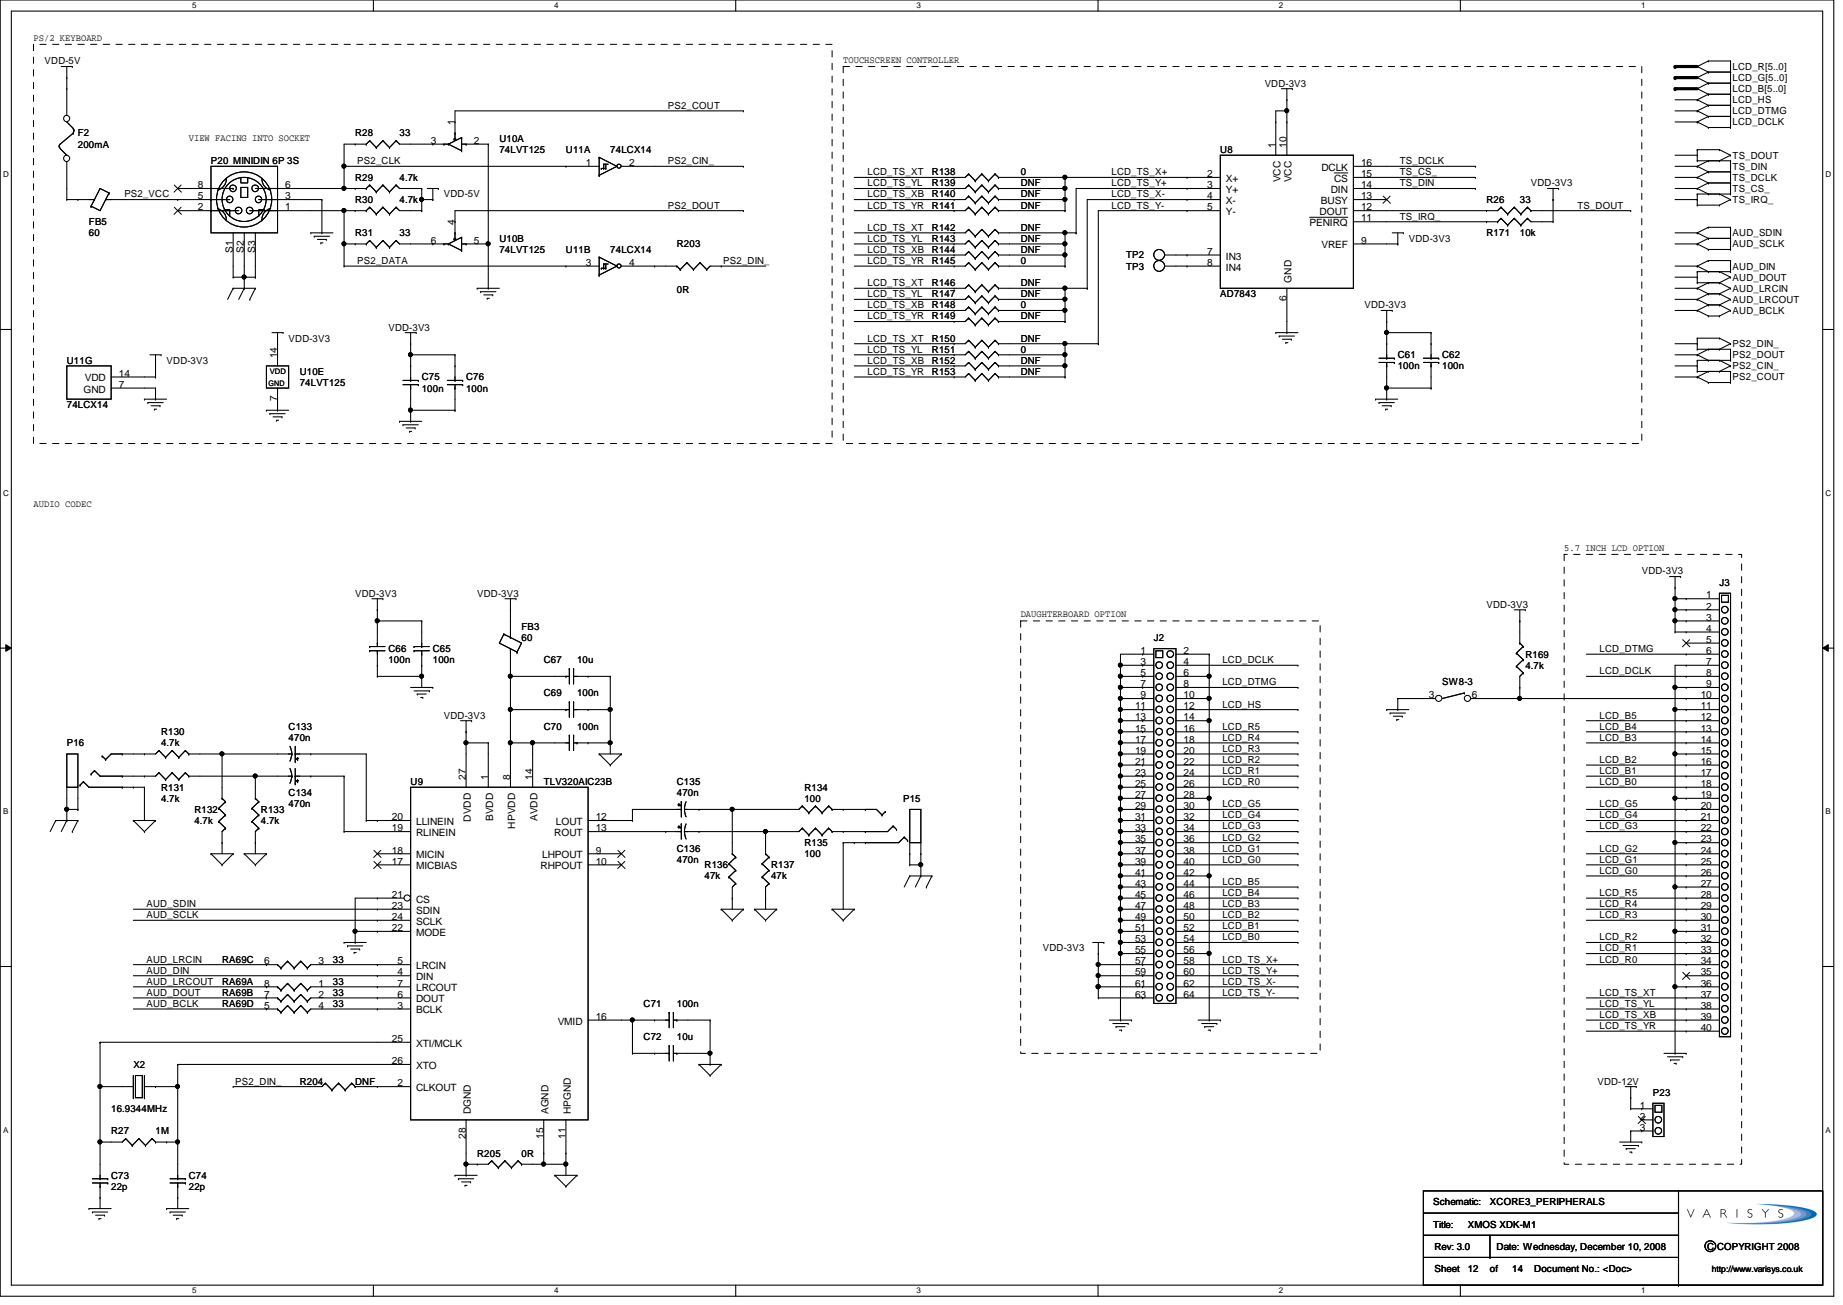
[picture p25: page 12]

VIEW FACING INTO SOCKET

PENIRQ 11 DOUT 12 BUSY 13 DIN 14 CS 15 DCLK 16

## X1LC0_IN

## X1LC1_IN


CAT 5e / CAT 6 CROSS WIRED STP PATCH CABLE

UP


XSYS UP/DOWN CONNECTORS

SENSE FOR UP/DOWN CONNECTIONS - LOOKS FOR UNDRIVEN/FLOATING TDI/TDO

END OF LINE PULLDOWN

END OF LINE AC TERMINATION

O/P FLOATS IF LEVEL > 0.25 VDD

ICE SENSE (ON = CONNECTED)

XSYS UP SENSE (ON = CONNECTED)

XSYS DOWN SENSE (ON = CONNECTED)

RESET - UP AND LOCAL CPU

DEBUG HIGH - UP AND LOCAL CPU

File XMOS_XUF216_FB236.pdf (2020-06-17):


Board can be configured for
Line or Tree/Star network.

Open Source
File: XMOS_XUF216_FB236.sch Sheet: / openPnP

Id: 1/16 Title: XMOS top level


L.out0- LWDS: 100 ohm Zdiff impedance in coupled microstrip line.

Optional pulldown if needed.

Unconnected LVDS input gives HI out on TTL side.
Active XLinks input should be LO during reset.
XMOS pins has internal pulldown.
Transciever needs to be in HiZ during XMOS reset.

This should give hardware support for hotswap with unconnected active XLinks, with bootloader in Flash.

File: LVDS.sch Sheet: /LVDS7/ openPnP

Id: 2/16 Title: LVDS <-> Xlinks


Cards can be power by USB or by the barrel jack 8-48V.
Alternative "+48V" can come from a connected daugther card.
Both USB and +48V should not be connected on the same PCB.
USB ground should be isolated from power ground for PC safety.

Power ports are Global in the schematics.

FB3V3 SENSE VDDIO/OTP_VCC and VDD can ramp up independently.

2 -Vout 3 +Vout 4 M1 RFM-0505S GND

In order to reduce stresses on the device, it is preferable to make them ramp up in a short time frame of each other,
no more than 50 ms apart.
RST_N and TRST_N should be kept low until all power supplies are stable and within tolerances of their final voltage.
If your design is powered by VBUS, then RST_N should go high within 10 ms of attaching to VBUS in order to ensure that USB timings are met.
RST_N should be at least 1 ms after VDDIO good to enable the built-in flash to settle

Open Source
File: power.sch Sheet: /POWER/ openPnP


L.out0- LWDS: 100 ohm Zdiff impedance in coupled microstrip line.

Optional pulldown if needed.

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

This should give hardware support for hotswap with unconnected active XLinks, with bootloader in Flash.

File: LVDS.sch Sheet: /LVDS2/ openPnP

Id: 4/16 Title: LVDS <-> Xlinks


USB: 90 ohm Zdiff impedance in coupled microstrip line.
Spacing 3,5 mil. Width 9 mil. H=180um. Side clearance 20 mil
PCB type: FR-4, KB-6160/6160A/6160C
+5V GND
47k 10k R25 GND

4X1 ASV-24MHz GND GND+3V3 +3V3 NC 1 NC 2

Open Source
File: XMOS_USB.sch Sheet: /XMOS USB/JTAG/ openPnP

Id: 5/16 Title: XTAG & XMOS USB


XTAG.TRST XMOS.TCK

Pin 5,7,9,13,15 must be connected for xCORE-200.
Pin 11 for multi-PCB debug events.
XTAG does not power any device.

5V_XTAG
CHAINED_SELECT XTAG.MSEL
XTAG.TDO
XTAG.TRST XTAG.TMS
XTAG.TCK
XTAG.DEBUG

TMS to pin 7 of the xSYS header
TCK to pin 9 of the xSYS header
DEBUG_N to pin 11 of the xSYS header

JTAG, XLink or UART.
JTAG disruptes realtime
execution.
The UART interface
executes at a rate of 2MB/s

TDO from last XMOS chip in chain

A connected header or mini DIN will ground this net

TDO from XMOS chip on this PCB

9 | 10
11 | 12
13 | 14
15 | 16

All one-way data flow wires has
inverted direction in FEMALE connector

Open Source
File: XTAG.sch Sheet: /XTAG/ openPnP

Id: 6/16 Title: XTAG / xSYS


High speed RGMII pins. 125MHz ETH.MDIO

9 | 10

ETH.rx_clk 11 | 12
ETH.tx_ctl 13 | 14

4 1-bit low speed ports needed for a RGMII card.

Open Source
File: Tile1.sch Sheet: /Tile1/ openPnP


Disable gives HiZ on output

For XLinks-2 wire: To avoid jitter/skew sensitivity,
only one transition per clock cycle can happen within the pair.

Open Source
File: Isolation.sch Sheet: /Tile1/Iso1/ openPnP


L.out0- LWDS: 100 ohm Zdiff impedance in coupled microstrip line.

Optional pulldown if needed.

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

This should give hardware support for hotswap with unconnected active XLinks, with bootloader in Flash.

File: LVDS.sch Sheet: /Tile1/LVDS1/ openPnP

Id: 9/16 Title: LVDS <-> Xlinks


L.out0- LWDS: 100 ohm Zdiff impedance in coupled microstrip line.

Optional pulldown if needed.

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

This should give hardware support for hotswap with unconnected active XLinks, with bootloader in Flash.
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

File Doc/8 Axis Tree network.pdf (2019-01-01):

XTAG UART; IDC; COLOR = ACTIVATED; UART.; HUB; 9(Not shown) IO2-card; X-AXIS; Y-AXIS; X-AXIS2; HEAD Z; HEAD C0; HEAD C1

Tree network + JTAG line.
Compiler can create
the routing table for PCBs.
Hub can be flashed, cards separated,
without any change to the code.
Isolation works when separated.
Suitable for network where the
branches does not talk to each other
with high bandwith.

JTAG | XL7

XL0 | XUF 216 USB | XL6

JTAG | XL4

Tested with 9 PCBs in tree
+ XTAG line.
Full JTAG debug.
Realtime Stdout over

Compiles and runs in the
simulator.

XL0 | XUF 216 | XL6

FLASH XL3 | JTAG | XL7

XL1 | | XL5
USB XL2 | UART JTAG | XL4

Boots over JTAG or from Flash










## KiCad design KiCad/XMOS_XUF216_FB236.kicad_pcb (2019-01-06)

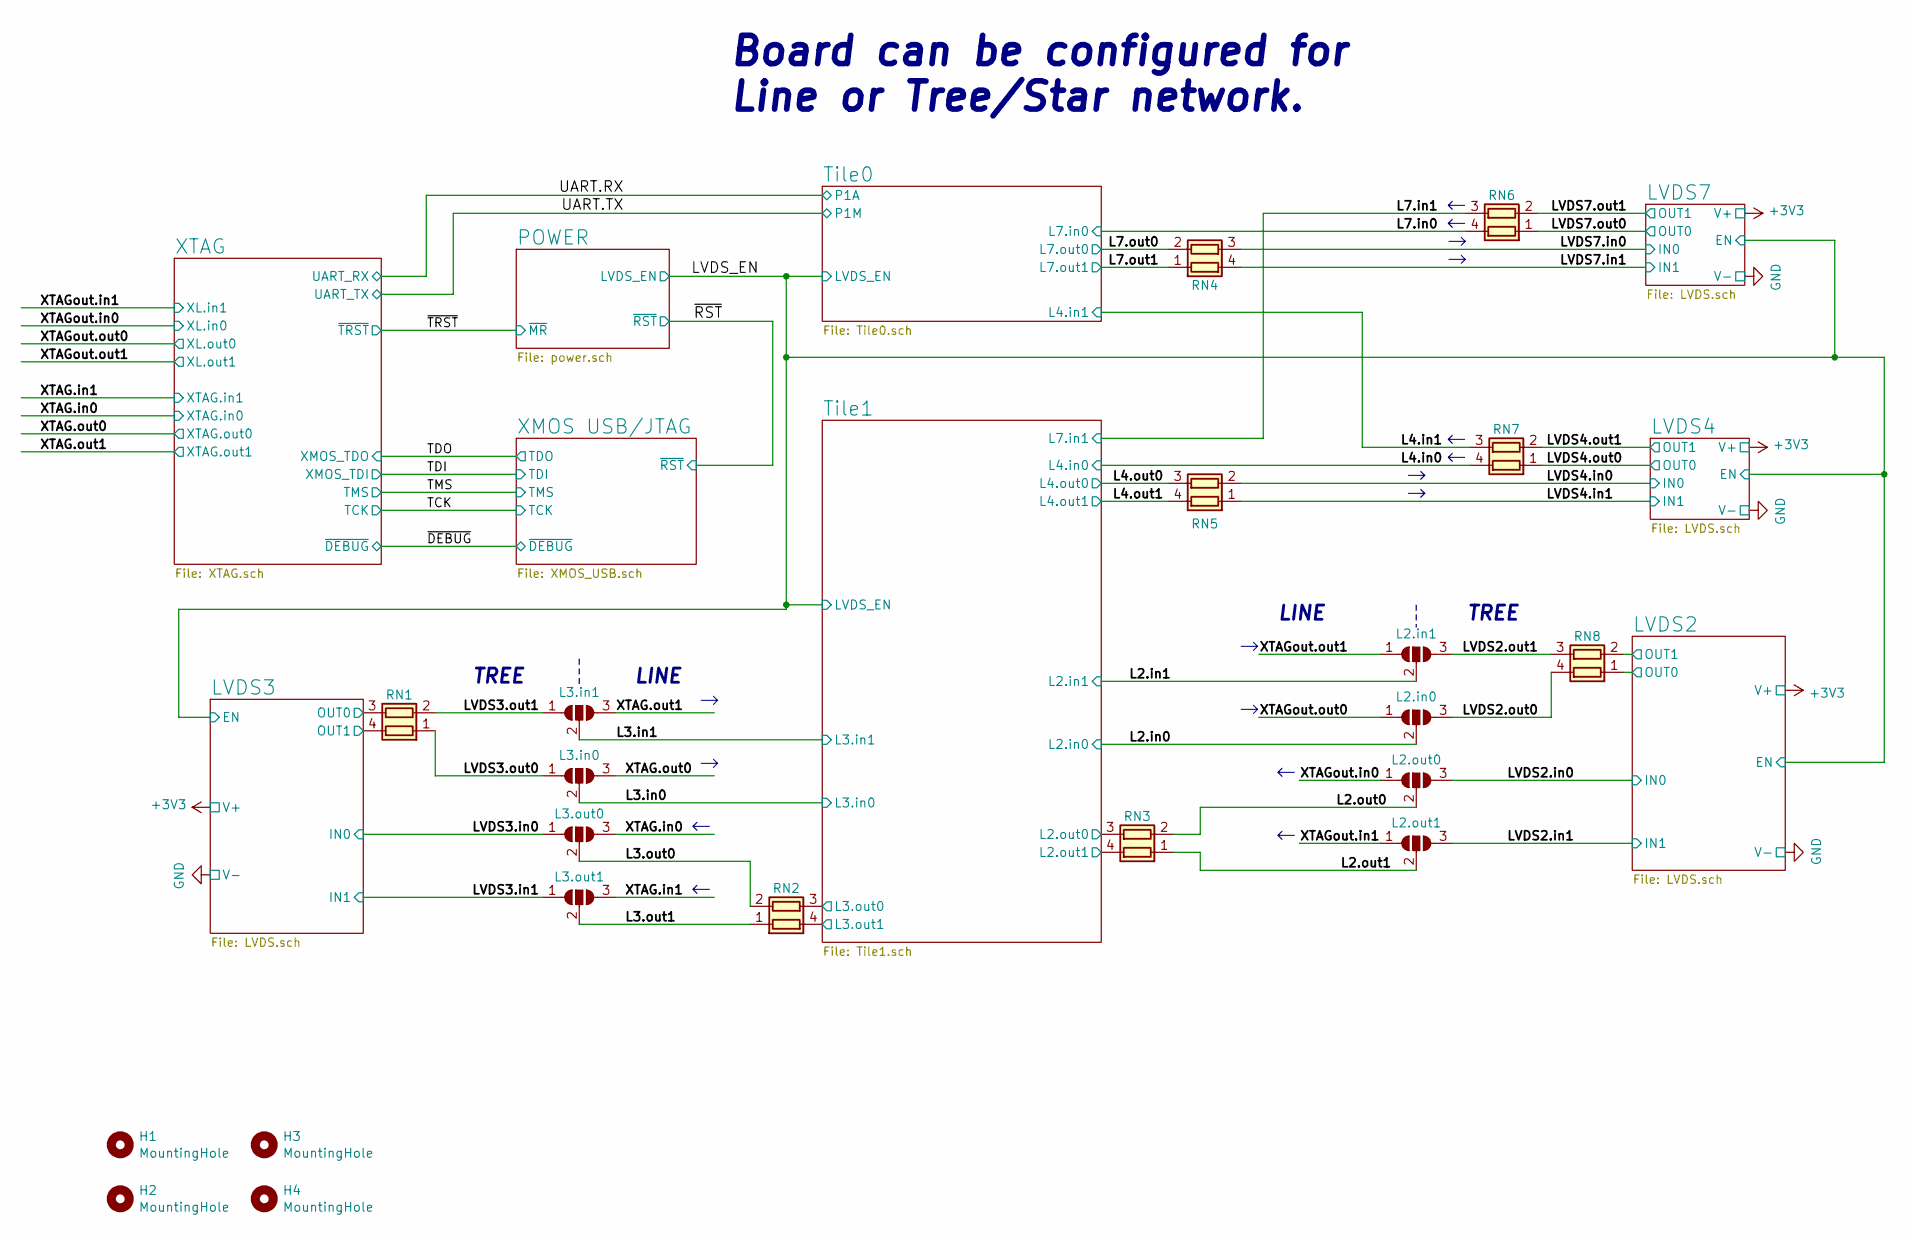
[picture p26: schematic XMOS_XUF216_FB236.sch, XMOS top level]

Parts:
H1, H2, H3, H4: MountingHole; MountingHole_3.2mm_M3
JP1: L3.in1; SolderJumper-3_P1.3mm_Open_RoundedPad1.0x1.5mm_NumberLabels
JP2: L3.in0; SolderJumper-3_P1.3mm_Open_RoundedPad1.0x1.5mm_NumberLabels
JP3: L3.out0; SolderJumper-3_P1.3mm_Open_RoundedPad1.0x1.5mm_NumberLabels
JP4: L3.out1; SolderJumper-3_P1.3mm_Open_RoundedPad1.0x1.5mm_NumberLabels
JP5: L2.in1; SolderJumper-3_P1.3mm_Open_RoundedPad1.0x1.5mm_NumberLabels
JP6: L2.in0; SolderJumper-3_P1.3mm_Open_RoundedPad1.0x1.5mm_NumberLabels
JP7: L2.out0; SolderJumper-3_P1.3mm_Open_RoundedPad1.0x1.5mm_NumberLabels
JP8: L2.out1; SolderJumper-3_P1.3mm_Open_RoundedPad1.0x1.5mm_NumberLabels
RN1, RN2, RN3, RN4, RN5, RN6, RN7, RN8: R_Pack02; R_Array_Convex_2x0402

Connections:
/L2.in0: JP6.2 (C); also elsewhere on the board
/L2.in1: JP5.2 (C); also elsewhere on the board
/L2.out0: JP7.2 (C), RN3.2 (R2.1)
/L2.out1: JP8.2 (C), RN3.1 (R1.1)
/L3.in0: JP2.2 (C); also elsewhere on the board
/L3.in1: JP1.2 (C); also elsewhere on the board
/L3.out0: JP3.2 (C), RN2.2 (R2.1)
/L3.out1: JP4.2 (C), RN2.1 (R1.1)
/L4.in0: RN7.4 (R1.2); also elsewhere on the board
/L4.in1: RN7.3 (R2.2); also elsewhere on the board
/L4.out0: RN5.3 (R2.2); also elsewhere on the board
/L4.out1: RN5.4 (R1.2); also elsewhere on the board
/L7.in0: RN6.4 (R1.2); also elsewhere on the board
/L7.in1: RN6.3 (R2.2); also elsewhere on the board
/L7.out0: RN4.2 (R2.1); also elsewhere on the board
/L7.out1: RN4.1 (R1.1); also elsewhere on the board
/LVDS2.in0: JP7.3 (B); also elsewhere on the board
/LVDS2.in1: JP8.3 (B); also elsewhere on the board
/LVDS2.out0: JP6.3 (B), RN8.4 (R1.2)
/LVDS2.out1: JP5.3 (B), RN8.3 (R2.2)
/LVDS2/OUT0: RN8.1 (R1.1); also elsewhere on the board
/LVDS2/OUT1: RN8.2 (R2.1); also elsewhere on the board
/LVDS3.in0: JP3.1 (A); also elsewhere on the board
/LVDS3.in1: JP4.1 (A); also elsewhere on the board
/LVDS3.out0: JP2.1 (A), RN1.1 (R1.1)
/LVDS3.out1: JP1.1 (A), RN1.2 (R2.1)
/LVDS3/OUT0: RN1.3 (R2.2); also elsewhere on the board
/LVDS3/OUT1: RN1.4 (R1.2); also elsewhere on the board
/LVDS4.in0: RN5.2 (R2.1); also elsewhere on the board
/LVDS4.in1: RN5.1 (R1.1); also elsewhere on the board
/LVDS4.out0: RN7.1 (R1.1); also elsewhere on the board
/LVDS4.out1: RN7.2 (R2.1); also elsewhere on the board
/LVDS7.in0: RN4.3 (R2.2); also elsewhere on the board
/LVDS7.in1: RN4.4 (R1.2); also elsewhere on the board
/LVDS7.out0: RN6.1 (R1.1); also elsewhere on the board
/LVDS7.out1: RN6.2 (R2.1); also elsewhere on the board
/Tile1/L2.out0: RN3.3 (R2.2); also elsewhere on the board
/Tile1/L2.out1: RN3.4 (R1.2); also elsewhere on the board
/Tile1/L3.out0: RN2.3 (R2.2); also elsewhere on the board
/Tile1/L3.out1: RN2.4 (R1.2); also elsewhere on the board
/XTAG.in0: JP3.3 (B); also elsewhere on the board
/XTAG.in1: JP4.3 (B); also elsewhere on the board
/XTAG.out0: JP2.3 (B); also elsewhere on the board
/XTAG.out1: JP1.3 (B); also elsewhere on the board
/XTAGout.in0: JP7.1 (A); also elsewhere on the board
/XTAGout.in1: JP8.1 (A); also elsewhere on the board
/XTAGout.out0: JP6.1 (A); also elsewhere on the board
/XTAGout.out1: JP5.1 (A); also elsewhere on the board

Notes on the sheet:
Board can be configured for Line or Tree/Star network.
TREE
LINE

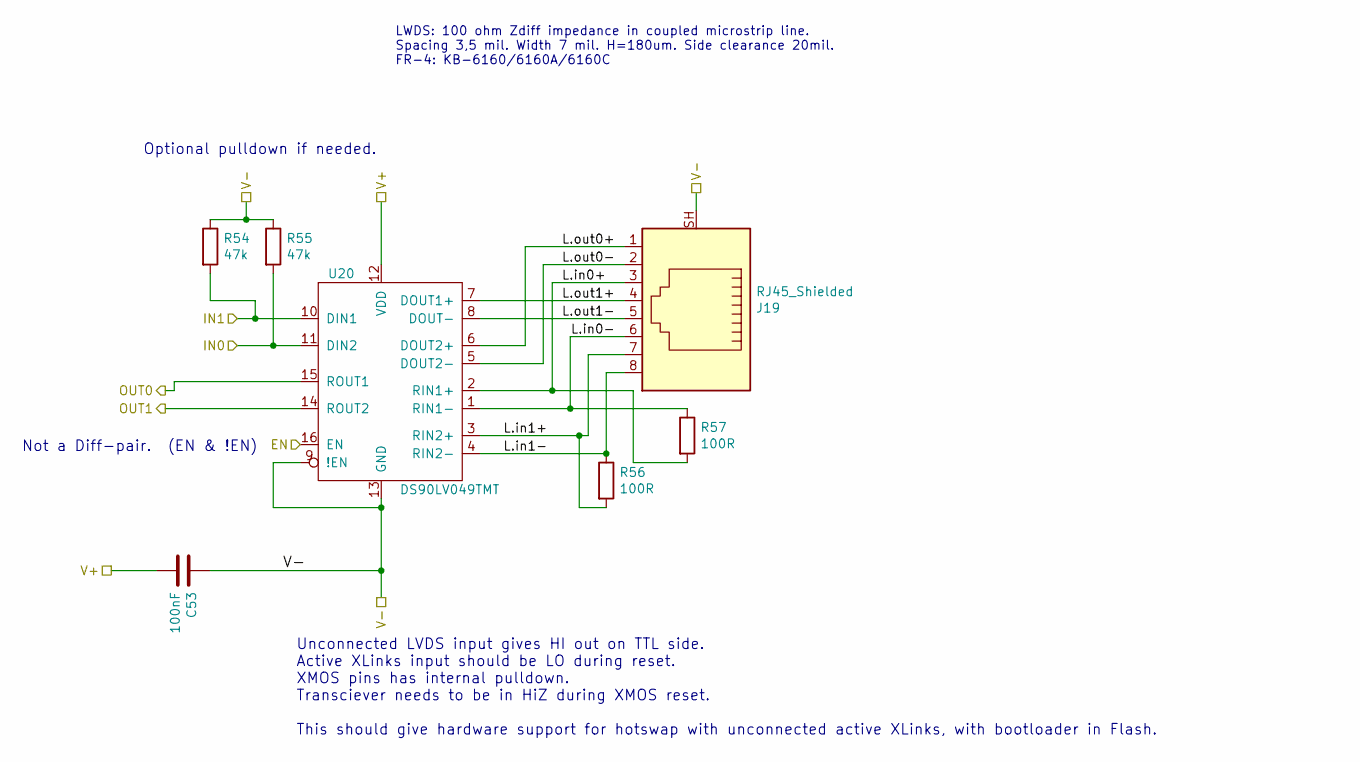
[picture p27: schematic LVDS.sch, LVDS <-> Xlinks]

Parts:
C1: 100nF; C_0603_1608Metric_Pad1.05x0.95mm_HandSolder
J1: RJ45_Shielded; RJ45_Amphenol_RJHSE5380
R1, R2: 47k; R_0402_1005Metric
R3, R4: 100R; R_0402_1005Metric
U1: DS90LV049TMT; TSSOP-16_4.4x5mm_P0.65mm

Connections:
/LVDS7.in0: R2.2, U1.11 (DIN2); also elsewhere on the board
/LVDS7.in1: R1.2, U1.10 (DIN1); also elsewhere on the board
/LVDS7.out0: U1.15 (ROUT1); also elsewhere on the board
/LVDS7.out1: U1.14 (ROUT2); also elsewhere on the board
/LVDS7/L.in0+: J1.3, R4.2, U1.2 (RIN1+)
/LVDS7/L.in0-: J1.6, R4.1, U1.1 (RIN1-)
/LVDS7/L.in1+: J1.7, R3.2, U1.3 (RIN2+)
/LVDS7/L.in1-: J1.8, R3.1, U1.4 (RIN2-)
/LVDS7/L.out0+: J1.1, U1.6 (DOUT2+)
/LVDS7/L.out0-: J1.2, U1.5 (DOUT2-)
/LVDS7/L.out1+: J1.4, U1.7 (DOUT1+)
/LVDS7/L.out1-: J1.5, U1.8 (DOUT-)
/LVDS_EN: U1.16 (EN); also elsewhere on the board
GND: C1.1, J1.SH, R1.1, R2.1, U1.9 (!EN), U1.13 (GND); also elsewhere on the board

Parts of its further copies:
C15, C46, C47, C48, C49, C50, C53: 100nF; C_0603_1608Metric_Pad1.05x0.95mm_HandSolder
J4, J13, J14, J16, J17, J18, J19: RJ45_Shielded; RJ45_Amphenol_RJHSE5380
R15, R16, R31, R32, R35, R36, R42, R43, R46, R47, R50, R51, R54, R55: 47k; R_0402_1005Metric
R17, R18, R33, R34, R37, R38, R44, R45, R48, R49, R52, R53, R56, R57: 100R; R_0402_1005Metric
U8, U14, U15, U16, U17, U18, U20: DS90LV049TMT; TSSOP-16_4.4x5mm_P0.65mm

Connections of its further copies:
+3.3VP: C46.2, C50.2, U14.12 (VDD), U14.16 (EN), U18.12 (VDD), U18.16 (EN); also elsewhere on the board
/LVDS2.in0: R16.2, U8.11 (DIN2); also elsewhere on the board
/LVDS2.in1: R15.2, U8.10 (DIN1); also elsewhere on the board
/LVDS2/L.in0+: J4.3, R18.2, U8.2 (RIN1+)
/LVDS2/L.in0-: J4.6, R18.1, U8.1 (RIN1-)
/LVDS2/L.in1+: J4.7, R17.2, U8.3 (RIN2+)
/LVDS2/L.in1-: J4.8, R17.1, U8.4 (RIN2-)
/LVDS2/L.out0+: J4.1, U8.6 (DOUT2+)
/LVDS2/L.out0-: J4.2, U8.5 (DOUT2-)
/LVDS2/L.out1+: J4.4, U8.7 (DOUT1+)
/LVDS2/L.out1-: J4.5, U8.8 (DOUT-)
/LVDS2/OUT0: U8.15 (ROUT1); also elsewhere on the board
/LVDS2/OUT1: U8.14 (ROUT2); also elsewhere on the board
/LVDS3.in0: R55.2, U20.11 (DIN2); also elsewhere on the board
/LVDS3.in1: R54.2, U20.10 (DIN1); also elsewhere on the board
/LVDS3/L.in0+: J19.3, R57.2, U20.2 (RIN1+)
/LVDS3/L.in0-: J19.6, R57.1, U20.1 (RIN1-)
/LVDS3/L.in1+: J19.7, R56.2, U20.3 (RIN2+)
/LVDS3/L.in1-: J19.8, R56.1, U20.4 (RIN2-)
/LVDS3/L.out0+: J19.1, U20.6 (DOUT2+)
/LVDS3/L.out0-: J19.2, U20.5 (DOUT2-)
/LVDS3/L.out1+: J19.4, U20.7 (DOUT1+)
/LVDS3/L.out1-: J19.5, U20.8 (DOUT-)
/LVDS3/OUT0: U20.15 (ROUT1); also elsewhere on the board
/LVDS3/OUT1: U20.14 (ROUT2); also elsewhere on the board
/LVDS4.in0: R36.2, U15.11 (DIN2); also elsewhere on the board
/LVDS4.in1: R35.2, U15.10 (DIN1); also elsewhere on the board
/LVDS4.out0: U15.15 (ROUT1); also elsewhere on the board
/LVDS4.out1: U15.14 (ROUT2); also elsewhere on the board
/LVDS4/L.in0+: J14.3, R38.2, U15.2 (RIN1+)
/LVDS4/L.in0-: J14.6, R38.1, U15.1 (RIN1-)
/LVDS4/L.in1+: J14.7, R37.2, U15.3 (RIN2+)
/LVDS4/L.in1-: J14.8, R37.1, U15.4 (RIN2-)
/LVDS4/L.out0+: J14.1, U15.6 (DOUT2+)
/LVDS4/L.out0-: J14.2, U15.5 (DOUT2-)
/LVDS4/L.out1+: J14.4, U15.7 (DOUT1+)
/LVDS4/L.out1-: J14.5, U15.8 (DOUT-)
/LVDS_EN: U8.16 (EN), U15.16 (EN), U16.16 (EN), U17.16 (EN), U20.16 (EN); also elsewhere on the board
/Tile0/LVDS0.in0: R51.2, U18.11 (DIN2); also elsewhere on the board
/Tile0/LVDS0.in1: R50.2, U18.10 (DIN1); also elsewhere on the board
/Tile0/LVDS0.out0: U18.15 (ROUT1); also elsewhere on the board
/Tile0/LVDS0.out1: U18.14 (ROUT2); also elsewhere on the board
/Tile0/LVDS0/L.in0+: J18.3, R53.2, U18.2 (RIN1+)
/Tile0/LVDS0/L.in0-: J18.6, R53.1, U18.1 (RIN1-)
/Tile0/LVDS0/L.in1+: J18.7, R52.2, U18.3 (RIN2+)
/Tile0/LVDS0/L.in1-: J18.8, R52.1, U18.4 (RIN2-)
/Tile0/LVDS0/L.out0+: J18.1, U18.6 (DOUT2+)
/Tile0/LVDS0/L.out0-: J18.2, U18.5 (DOUT2-)
/Tile0/LVDS0/L.out1+: J18.4, U18.7 (DOUT1+)
/Tile0/LVDS0/L.out1-: J18.5, U18.8 (DOUT-)
/Tile0/LVDS5.in0: R47.2, U17.11 (DIN2); also elsewhere on the board
/Tile0/LVDS5.in1: R46.2, U17.10 (DIN1); also elsewhere on the board
/Tile0/LVDS5.out0: U17.15 (ROUT1); also elsewhere on the board
/Tile0/LVDS5.out1: U17.14 (ROUT2); also elsewhere on the board
/Tile0/LVDS5/L.in0+: J17.3, R49.2, U17.2 (RIN1+)
/Tile0/LVDS5/L.in0-: J17.6, R49.1, U17.1 (RIN1-)
/Tile0/LVDS5/L.in1+: J17.7, R48.2, U17.3 (RIN2+)
/Tile0/LVDS5/L.in1-: J17.8, R48.1, U17.4 (RIN2-)
/Tile0/LVDS5/L.out0+: J17.1, U17.6 (DOUT2+)
/Tile0/LVDS5/L.out0-: J17.2, U17.5 (DOUT2-)
/Tile0/LVDS5/L.out1+: J17.4, U17.7 (DOUT1+)
/Tile0/LVDS5/L.out1-: J17.5, U17.8 (DOUT-)
/Tile0/LVDS6.in0: R43.2, U16.11 (DIN2); also elsewhere on the board
/Tile0/LVDS6.in1: R42.2, U16.10 (DIN1); also elsewhere on the board
/Tile0/LVDS6.out0: U16.15 (ROUT1); also elsewhere on the board
/Tile0/LVDS6.out1: U16.14 (ROUT2); also elsewhere on the board
/Tile0/LVDS6/L.in0+: J16.3, R45.2, U16.2 (RIN1+)
/Tile0/LVDS6/L.in0-: J16.6, R45.1, U16.1 (RIN1-)
/Tile0/LVDS6/L.in1+: J16.7, R44.2, U16.3 (RIN2+)
/Tile0/LVDS6/L.in1-: J16.8, R44.1, U16.4 (RIN2-)
/Tile0/LVDS6/L.out0+: J16.1, U16.6 (DOUT2+)
/Tile0/LVDS6/L.out0-: J16.2, U16.5 (DOUT2-)
/Tile0/LVDS6/L.out1+: J16.4, U16.7 (DOUT1+)
/Tile0/LVDS6/L.out1-: J16.5, U16.8 (DOUT-)
/Tile1/LVDS1/L.in0+: J13.3, R34.2, U14.2 (RIN1+)
/Tile1/LVDS1/L.in0-: J13.6, R34.1, U14.1 (RIN1-)
/Tile1/LVDS1/L.in1+: J13.7, R33.2, U14.3 (RIN2+)
/Tile1/LVDS1/L.in1-: J13.8, R33.1, U14.4 (RIN2-)
/Tile1/LVDS1/L.out0+: J13.1, U14.6 (DOUT2+)
/Tile1/LVDS1/L.out0-: J13.2, U14.5 (DOUT2-)
/Tile1/LVDS1/L.out1+: J13.4, U14.7 (DOUT1+)
/Tile1/LVDS1/L.out1-: J13.5, U14.8 (DOUT-)
/Tile1/LVDS.in0: R32.2, U14.11 (DIN2); also elsewhere on the board
/Tile1/LVDS.in1: R31.2, U14.10 (DIN1); also elsewhere on the board
/Tile1/LVDS.out0: U14.15 (ROUT1); also elsewhere on the board
/Tile1/LVDS.out1: U14.14 (ROUT2); also elsewhere on the board
GND: C15.1, C47.1, C48.1, C49.1, C53.1, J4.SH, J14.SH, J16.SH, J17.SH, J19.SH, R15.1, R16.1, R35.1, R36.1, R42.1, R43.1, R46.1, R47.1, R54.1, R55.1, U8.9 (!EN), U8.13 (GND), U15.9 (!EN), U15.13 (GND), U16.9 (!EN), U16.13 (GND), U17.9 (!EN), U17.13 (GND), U20.9 (!EN), U20.13 (GND); also elsewhere on the board
GNDD: C46.1, C50.1, J13.SH, J18.SH, R31.1, R32.1, R50.1, R51.1, U14.9 (!EN), U14.13 (GND), U18.9 (!EN), U18.13 (GND); also elsewhere on the board

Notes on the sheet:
Unconnected LVDS input gives HI out on TTL side. Active XLinks input should be LO during reset. XMOS pins has internal pulldown. Transciever needs to be in HiZ during XMOS reset. This should give hardware support for hotswap with unconnected active XLinks, with bootloader in Flash.
Optional pulldown if needed.
Not a Diff-pair. (EN & !EN)
LWDS: 100 ohm Zdiff impedance in coupled microstrip line. Spacing 3,5 mil. Width 7 mil. H=180um. Side clearance 20mil. FR-4: KB-6160/6160A/6160C

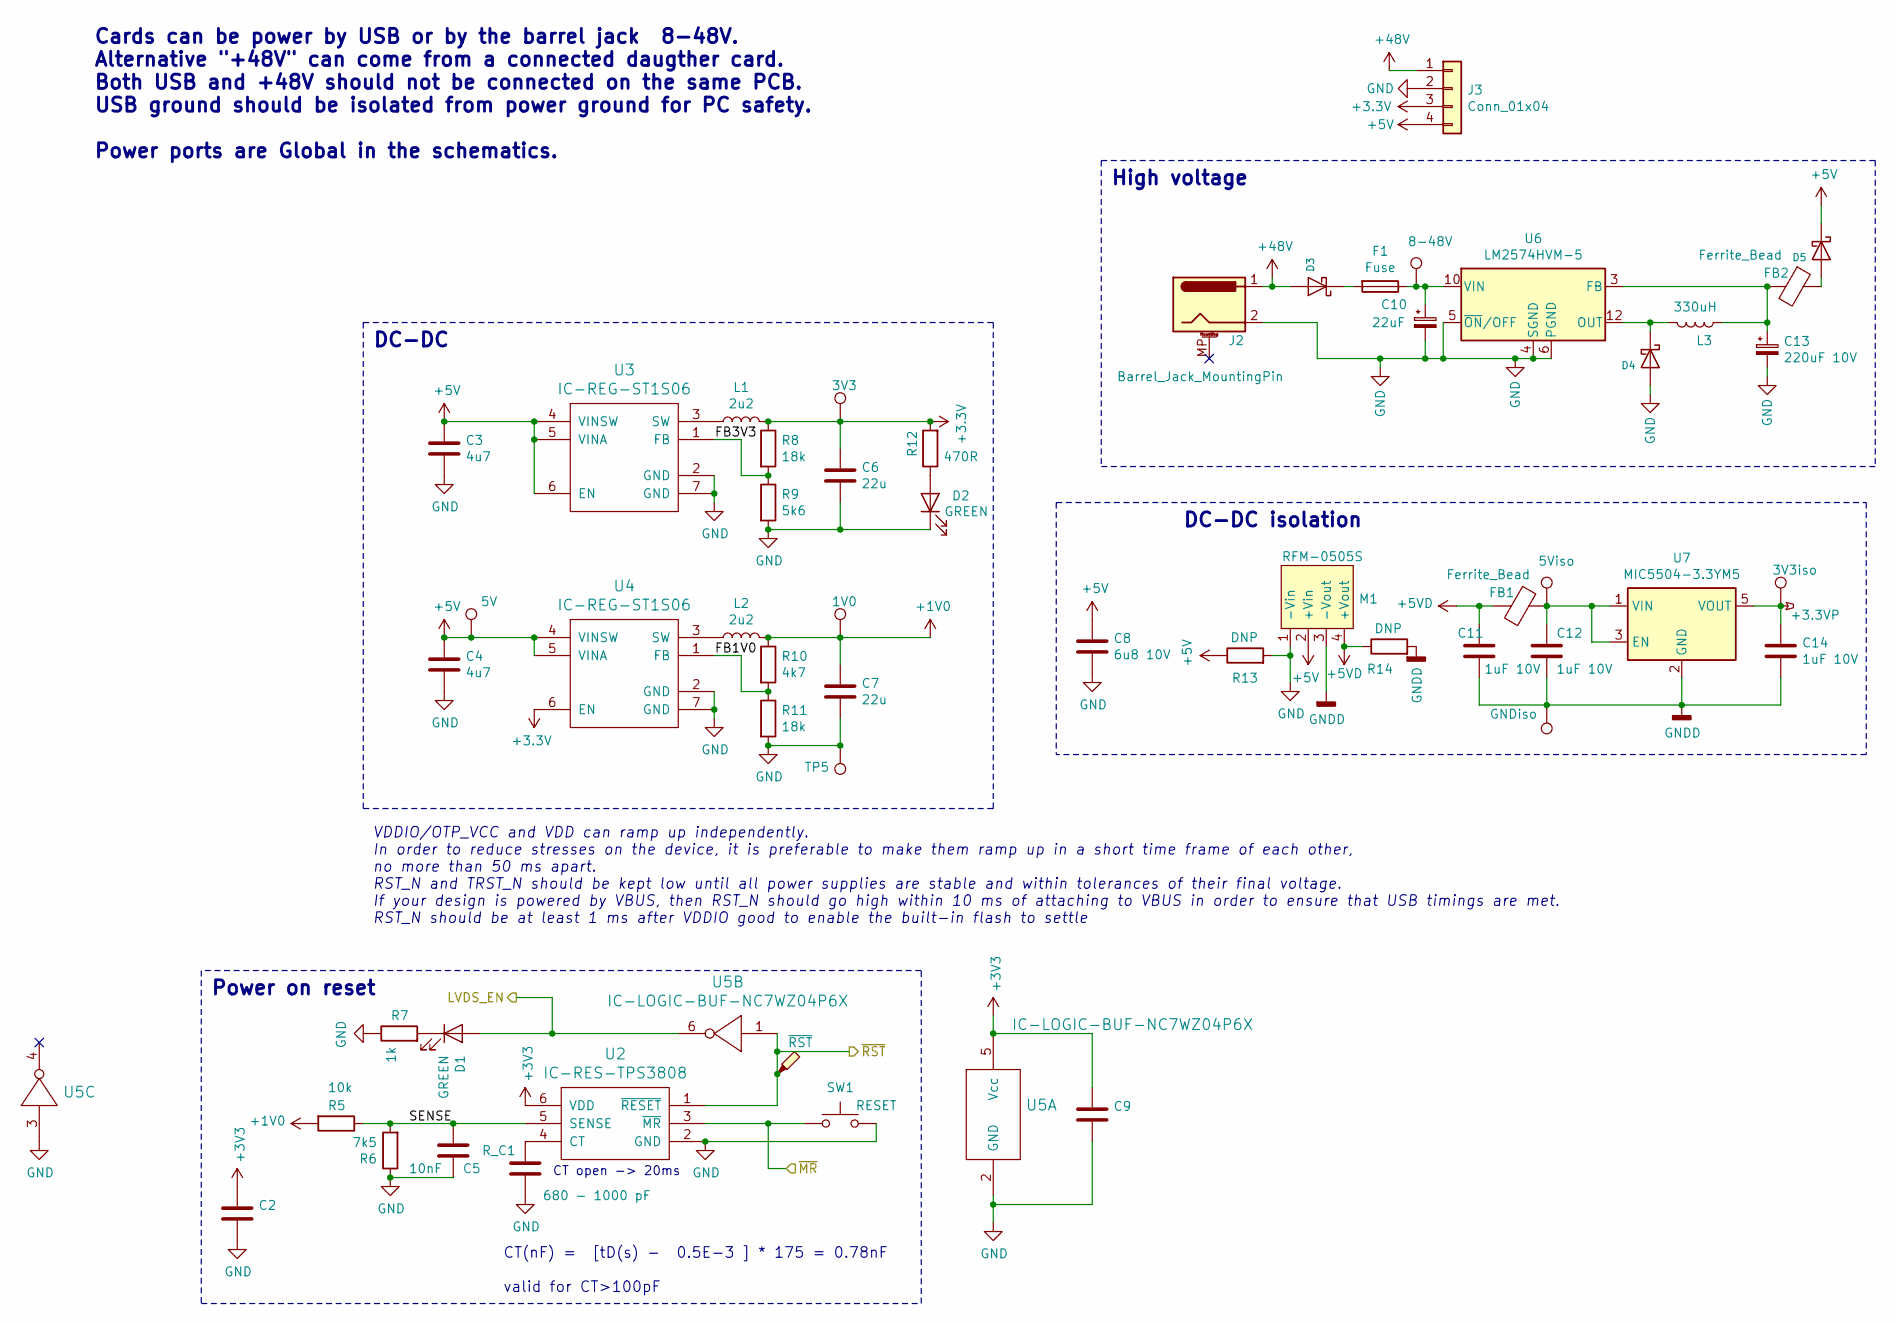
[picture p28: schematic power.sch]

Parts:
C2, C9: C; C_0603_1608Metric_Pad1.05x0.95mm_HandSolder
C3, C4: 4u7; C_0805_2012Metric_Pad1.15x1.40mm_HandSolder
C5: 10nF; C_0603_1608Metric
C6, C7: 22u; C_0805_2012Metric_Pad1.15x1.40mm_HandSolder
C8: 6u8 10V; C_0603_1608Metric_Pad1.05x0.95mm_HandSolder
C10: 22uF; C_Radial_D6.3mm_H11.0mm_P2.50mm; Part Number ESK226M100AE3AA
C11, C12, C14: 1uF 10V; C_0603_1608Metric_Pad1.05x0.95mm_HandSolder
C13: 220uF 10V; C_Radial_D6.3mm_H11.0mm_P2.50mm; Part Number 860040273002
D1, D2: GREEN; LED_0603_1608Metric_Pad1.05x0.95mm_HandSolder
D3, D5: SCHOTTKY_DIODE; D_SOD-123; Part Number MUR1100ERLG
D4: SCHOTTKY_DIODE; D_SOD-123F; Part Number MUR1100ERLG
F1: Fuse; Fuse_0805_2012Metric_Pad1.15x1.40mm_HandSolder
FB1: Ferrite_Bead; L_0603_1608Metric_Pad1.05x0.95mm_HandSolder
FB2: Ferrite_Bead; L_0805_2012Metric_Pad1.15x1.40mm_HandSolder
J2: Barrel_Jack_MountingPin; BarrelJack_Horizontal
J3: Conn_01x04; PinSocket_1x04_P2.54mm_Vertical
L1, L2: 2u2; L_Taiyo-Yuden_NR-60xx_HandSoldering
L3: 330uH; L_Bourns_SRR1210A
M1: RFM-0505S; RECON RFM DCDC
R5: 10k; R_0603_1608Metric_Pad1.05x0.95mm_HandSolder
R6: 7k5; R_0603_1608Metric_Pad1.05x0.95mm_HandSolder
R7: 1k; R_0603_1608Metric_Pad1.05x0.95mm_HandSolder
R8, R11: 18k; R_0603_1608Metric_Pad1.05x0.95mm_HandSolder
R9: 5k6; R_0603_1608Metric_Pad1.05x0.95mm_HandSolder
R10: 4k7; R_0603_1608Metric_Pad1.05x0.95mm_HandSolder
R12: 470R; R_0603_1608Metric_Pad1.05x0.95mm_HandSolder
R13, R14: DNP; R_0603_1608Metric_Pad1.05x0.95mm_HandSolder
R_C1: 680 - 1000 pF; C_0603_1608Metric_Pad1.05x0.95mm_HandSolder
SW1: RESET; SW_SPST_B3U-1000P
TP1: 5V; TestPoint_Loop_D1.80mm_Drill1.0mm_Beaded
TP2: ~RST; TestPoint_THTPad_2.0x2.0mm_Drill1.0mm
TP3: 3V3; TestPoint_Loop_D1.80mm_Drill1.0mm_Beaded
TP4: 1V0; TestPoint_Loop_D1.80mm_Drill1.0mm_Beaded
TP5: GND; TestPoint_THTPad_1.5x1.5mm_Drill0.7mm
TP6: 8-48V; TestPoint_Loop_D1.80mm_Drill1.0mm_Beaded
TP7: 5Viso; TestPoint_Loop_D1.80mm_Drill1.0mm_Beaded
TP8: GNDiso; TestPoint_THTPad_1.5x1.5mm_Drill0.7mm
TP9: 3V3iso; TestPoint_Loop_D1.80mm_Drill1.0mm_Beaded
U2: IC-RES-TPS3808; SOT-23-6_Handsoldering
U3, U4: IC-REG-ST1S06; DFN-6-1EP_3x3mm_P1mm_EP1.5x2.4mm
U5: IC-LOGIC-BUF-NC7WZ04P6X; SOT-363_SC-70-6_Handsoldering
U6: LM2574HVM-5; SOIC-14W_7.5x9.0mm_P1.27mm
U7: MIC5504-3.3YM5; SOT-23-5

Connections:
+1V0: C7.1, L2.2, R5.2, R10.1, TP4.1; also elsewhere on the board
+3.3VP: C14.1, TP9.1, U7.5 (VOUT); also elsewhere on the board
+5V: C3.1, C4.1, C8.1, D5.1 (K), J3.4, M1.2 (+Vin), R13.1, TP1.1, U3.4 (VINSW), U3.5 (VINA), U3.6 (EN), U4.4 (VINSW), U4.5 (VINA); also elsewhere on the board
+5VD: C11.1, FB1.2, M1.4 (+Vout), R14.1
+48V: D3.2 (A), J2.1, J3.1
/LVDS_EN: D1.2 (A), U5.6; also elsewhere on the board
/POWER/FB1V0: R10.2, R11.1, U4.1 (FB)
/POWER/FB3V3: R8.2, R9.1, U3.1 (FB)
/POWER/SENSE: C5.1, R5.1, R6.2, U2.5 (SENSE)
/~RST: TP2.1, U2.1 (~RESET), U5.1; also elsewhere on the board
/~TRST: SW1.1, U2.3 (~MR); also elsewhere on the board
GND: C2.2, C3.2, C4.2, C5.2, C6.2, C7.2, C8.2, C9.2, C10.2, C13.2, D2.1 (K), D4.2 (A), J2.2, J3.2, M1.1 (-Vin), R6.1, R7.1, R9.2, R11.2, R13.2, R_C1.1, SW1.2, TP5.1, U2.2 (GND), U3.2 (GND), U3.7 (GND), U4.2 (GND), U4.7 (GND), U5.2 (GND), U5.3, U6.4 (SGND), U6.5 (~ON~/OFF), U6.6 (PGND); also elsewhere on the board
GNDD: C11.2, C12.2, C14.2, M1.3 (-Vout), R14.2, TP8.1, U7.2 (GND); also elsewhere on the board
unnamed: C10.1, F1.1, TP6.1, U6.10 (VIN)
unnamed: C12.1, FB1.1, TP7.1, U7.1 (VIN), U7.3 (EN)
unnamed: C13.1, FB2.2, L3.1, U6.3 (FB)
unnamed: D1.1 (K), R7.2
unnamed: D2.2 (A), R12.1
unnamed: D3.1 (K), F1.2
unnamed: D4.1 (K), L3.2, U6.12 (OUT)
unnamed: D5.2 (A), FB2.1
unnamed: L1.1, U3.3 (SW)
unnamed: L2.1, U4.3 (SW)
unnamed: R_C1.2, U2.4 (CT)

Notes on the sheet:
High voltage
DC-DC isolation
DC-DC
Cards can be power by USB or by the barrel jack 8-48V. Alternative "+48V" can come from a connected daugther card. Both USB and +48V should not be connected on the same PCB. USB ground should be isolated from power ground for PC safety. Power ports are Global in the schematics.
VDDIO/OTP_VCC and VDD can ramp up independently. In order to reduce stresses on the device, it is preferable to make them ramp up in a short time frame of each other, no more than 50 ms apart. RST_N and TRST_N should be kept low until all power supplies are stable and within tolerances of their fin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
CT open -> 20ms
Power on reset
CT(nF) = [tD(s) - 0.5E-3 ] * 175 = 0.78nF valid for CT>100pF

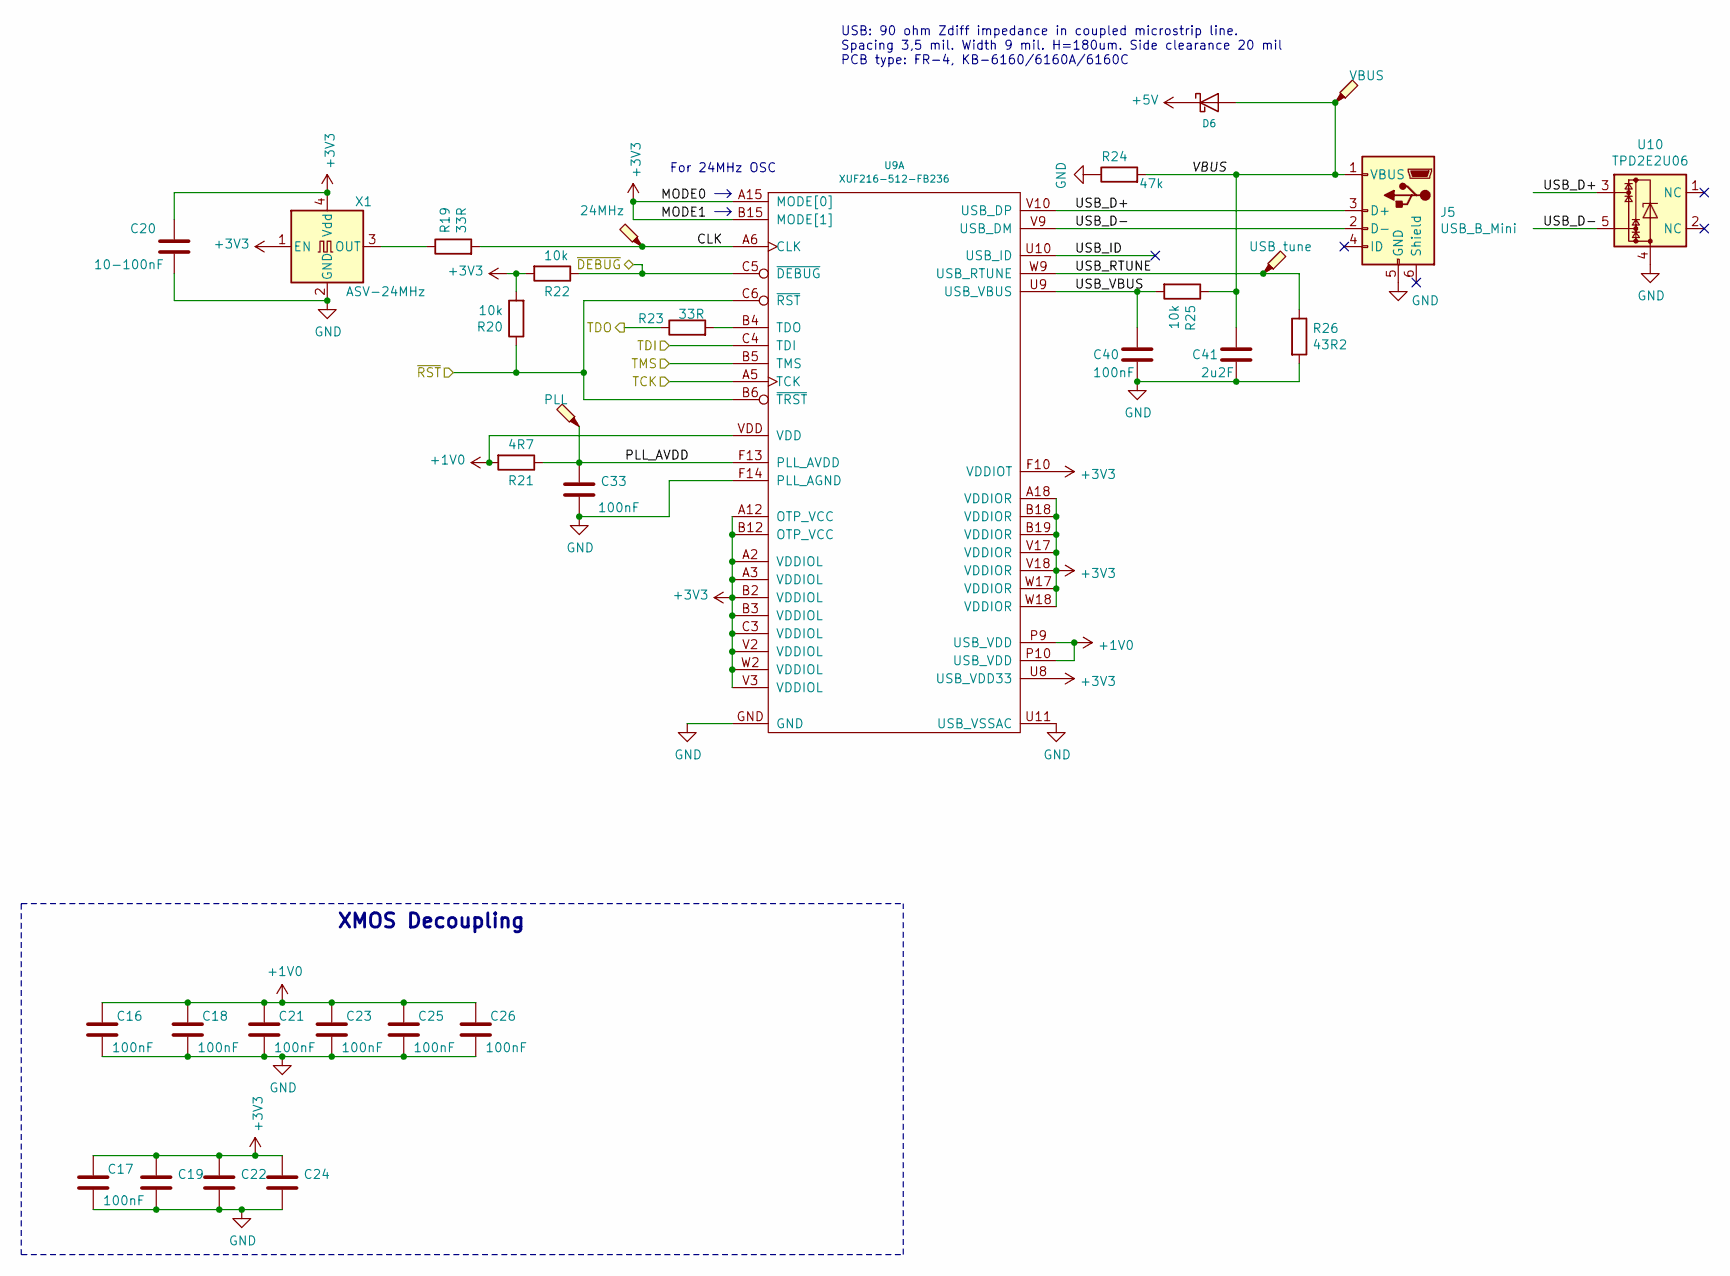
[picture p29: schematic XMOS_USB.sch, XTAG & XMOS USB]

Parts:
C16, C18, C21, C23, C25, C26, C33, C40: 100nF; C_0402_1005Metric
C17: 100nF; C_0603_1608Metric_Pad1.05x0.95mm_HandSolder
C19, C22, C24: C; C_0603_1608Metric_Pad1.05x0.95mm_HandSolder
C20: 10-100nF; C_0402_1005Metric
C41: 2u2F; C_0402_1005Metric
D6: SCHOTTKY_DIODE; D_SOD-123
J5: USB_B_Mini; USB_Micro-B_Molex-105017-0001
R19, R23: 33R; R_0603_1608Metric_Pad1.05x0.95mm_HandSolder
R20, R22, R25: 10k; R_0603_1608Metric_Pad1.05x0.95mm_HandSolder
R21: 4R7; R_0603_1608Metric_Pad1.05x0.95mm_HandSolder
R24: 47k; R_0603_1608Metric_Pad1.05x0.95mm_HandSolder
R26: 43R2; R_0603_1608Metric_Pad1.05x0.95mm_HandSolder
TP10: PLL; TestPoint_Pad_0.6x0.6mm
TP11: 24MHz; TestPoint_Pad_0.6x0.6mm
TP12: USB tune; TestPoint_Pad_0.6x0.6mm
TP13: VBUS; TestPoint_Pad_1.0x1.0mm
U9: XUF216-512-FB236; BGA_236
U10: TPD2E2U06; SOT-553
X1: ASV-24MHz; Oscillator_SMD_SeikoEpson_SG210-4Pin_2.5x2.0mm

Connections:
+1V0: C16.1, C18.1, C21.1, C23.1, C25.1, C26.1, R21.2, U9.P9 (USB_VDD), U9.P10 (USB_VDD), U9.VDD; also elsewhere on the board
+5V: D6.1 (K); also elsewhere on the board
/TCK: U9.A5 (TCK); also elsewhere on the board
/TDI: U9.C4 (TDI); also elsewhere on the board
/TDO: R23.1; also elsewhere on the board
/TMS: U9.B5 (TMS); also elsewhere on the board
/XMOS USB/JTAG/CLK: R19.2, TP11.1, U9.A6 (CLK)
/XMOS USB/JTAG/PLL_AVDD: C33.1, R21.1, TP10.1, U9.F13 (PLL_AVDD)
/XMOS USB/JTAG/USB_D+: J5.3 (D+), U9.V10 (USB_DP), U10.3
/XMOS USB/JTAG/USB_D-: J5.2 (D-), U9.V9 (USB_DM), U10.5
/XMOS USB/JTAG/USB_ID: U9.U10 (USB_ID)
/XMOS USB/JTAG/USB_RTUNE: R26.1, TP12.1, U9.W9 (USB_RTUNE)
/XMOS USB/JTAG/USB_VBUS: C40.1, R25.2, U9.U9 (USB_VBUS)
/XMOS USB/JTAG/VBUS: C41.1, D6.2 (A), J5.1 (VBUS), R24.2, R25.1, TP13.1
/~DEBUG: R22.1, U9.C5 (~DEBUG); also elsewhere on the board
/~RST: R20.1, U9.B6 (~TRST), U9.C6 (~RST); also elsewhere on the board
GND: C16.2, C17.2, C18.2, C19.2, C20.2, C21.2, C22.2, C23.2, C24.2, C25.2, C26.2, C33.2, C40.2, C41.2, J5.5 (GND), R24.1, R26.2, U9.F14 (PLL_AGND), U9.GND, U9.U11 (USB_VSSAC), U10.4, X1.2 (GND); also elsewhere on the board
unnamed: R19.1, X1.3 (OUT)
unnamed: R23.2, U9.B4 (TDO)

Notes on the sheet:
For 24MHz OSC
XMOS Decoupling
USB: 90 ohm Zdiff impedance in coupled microstrip line. Spacing 3,5 mil. Width 9 mil. H=180um. Side clearance 20 mil PCB type: FR-4, KB-6160/6160A/6160C

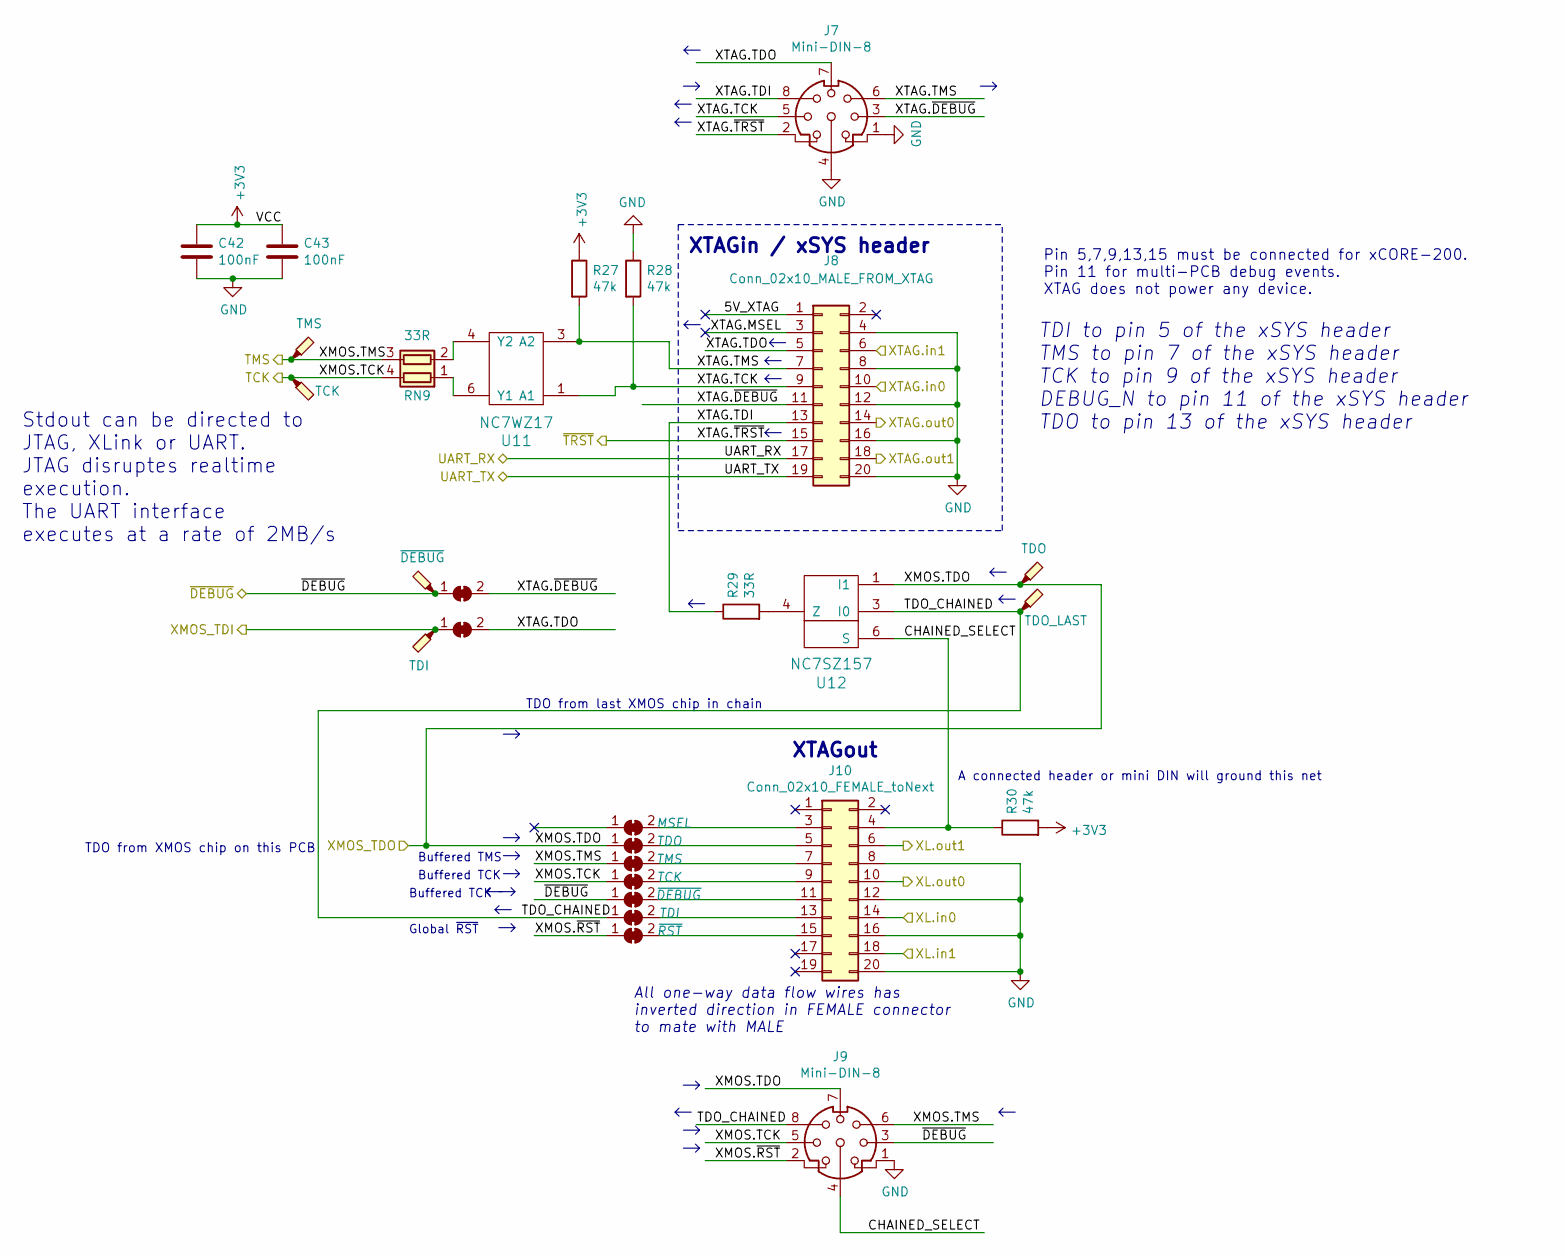
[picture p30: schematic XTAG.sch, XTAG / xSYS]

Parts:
C42, C43: 100nF; C_0603_1608Metric_Pad1.05x0.95mm_HandSolder
J7, J9: Mini-DIN-8; MDC-278
J8: Conn_02x10_MALE_FROM_XTAG; IDC-Header_2x10_P2.54mm_Horizontal
J10: Conn_02x10_FEMALE_toNext; PinSocket_2x10_P2.54mm_Horizontal; Part Number SFH11-PBPC-D10-RA-BK
JP9, JP15: ~DEBUG; SolderJumper-2_P1.3mm_Bridged_RoundedPad1.0x1.5mm
JP10, JP12: TDO; SolderJumper-2_P1.3mm_Bridged_RoundedPad1.0x1.5mm
JP11: MSEL; SolderJumper-2_P1.3mm_Bridged_RoundedPad1.0x1.5mm
JP13: TMS; SolderJumper-2_P1.3mm_Bridged_RoundedPad1.0x1.5mm
JP14: TCK; SolderJumper-2_P1.3mm_Bridged_RoundedPad1.0x1.5mm
JP16: TDI; SolderJumper-2_P1.3mm_Bridged_RoundedPad1.0x1.5mm
JP17: ~RST; SolderJumper-2_P1.3mm_Bridged_RoundedPad1.0x1.5mm
R27, R28, R30: 47k; R_0603_1608Metric_Pad1.05x0.95mm_HandSolder
R29: 33R; R_0603_1608Metric_Pad1.05x0.95mm_HandSolder
RN9: 33R; R_Array_Convex_2x0402
TP14: TMS; TestPoint_THTPad_1.5x1.5mm_Drill0.7mm
TP15: TCK; TestPoint_THTPad_1.5x1.5mm_Drill0.7mm
TP16: ~DEBUG; TestPoint_THTPad_1.5x1.5mm_Drill0.7mm
TP17: TDI; TestPoint_THTPad_1.5x1.5mm_Drill0.7mm
TP18: TDO; TestPoint_THTPad_1.5x1.5mm_Drill0.7mm
TP19: TDO_LAST; TestPoint_THTPad_1.5x1.5mm_Drill0.7mm
U11: NC7WZ17; SOT-363_SC-70-6_Handsoldering
U12: NC7SZ157; SOT-363_SC-70-6_Handsoldering

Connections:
/TCK: J9.5, JP14.1 (A), RN9.4 (R1.2), TP15.1; also elsewhere on the board
/TDI: JP10.1 (A), TP17.1; also elsewhere on the board
/TDO: J9.7, JP12.1 (A), TP18.1, U12.1 (I1); also elsewhere on the board
/TMS: J9.6, JP13.1 (A), RN9.3 (R2.2), TP14.1; also elsewhere on the board
/UART.RX: J8.17; also elsewhere on the board
/UART.TX: J8.19; also elsewhere on the board
/XTAG.in0: J8.10; also elsewhere on the board
/XTAG.in1: J8.6; also elsewhere on the board
/XTAG.out0: J8.14; also elsewhere on the board
/XTAG.out1: J8.18; also elsewhere on the board
/XTAG/5V_XTAG: J8.1
/XTAG/CHAINED_SELECT: J9.4, J10.4, R30.1, U12.6 (S)
/XTAG/TDO_CHAINED: J9.8, JP16.1 (A), TP19.1, U12.3 (I0)
/XTAG/XMOS.~RST: J9.2, JP17.1 (A)
/XTAG/XTAG.MSEL: J8.3
/XTAG/XTAG.TCK: J7.5, J8.9, R28.2, U11.1 (A1)
/XTAG/XTAG.TDI: J7.8, J8.13, R29.1
/XTAG/XTAG.TDO: J7.7, J8.5, JP10.2 (B)
/XTAG/XTAG.TMS: J7.6, J8.7, R27.2, U11.3 (A2)
/XTAG/XTAG.~DEBUG: J7.3, J8.11, JP9.2 (B)
/XTAGout.in0: J10.14; also elsewhere on the board
/XTAGout.in1: J10.18; also elsewhere on the board
/XTAGout.out0: J10.10; also elsewhere on the board
/XTAGout.out1: J10.6; also elsewhere on the board
/~DEBUG: J9.3, JP9.1 (A), JP15.1 (A), TP16.1; also elsewhere on the board
/~TRST: J7.2, J8.15; also elsewhere on the board
GND: C42.2, C43.2, J7.1, J7.4, J8.4, J8.8, J8.12, J8.16, J8.20, J9.1, J10.8, J10.12, J10.16, J10.20, R28.1, U11.2 (GND), U12.2 (GND); also elsewhere on the board
unnamed: J10.3, JP11.2 (B)
unnamed: J10.5, JP12.2 (B)
unnamed: J10.7, JP13.2 (B)
unnamed: J10.9, JP14.2 (B)
unnamed: J10.11, JP15.2 (B)
unnamed: J10.13, JP16.2 (B)
unnamed: J10.15, JP17.2 (B)
unnamed: R29.2, U12.4 (Z)
unnamed: RN9.1 (R1.1), U11.6 (Y1)
unnamed: RN9.2 (R2.1), U11.4 (Y2)

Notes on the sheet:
All one-way data flow wires has inverted direction in FEMALE connector to mate with MALE
Pin 5,7,9,13,15 must be connected for xCORE-200. Pin 11 for multi-PCB debug events. XTAG does not power any device.
TDI to pin 5 of the xSYS header TMS to pin 7 of the xSYS header TCK to pin 9 of the xSYS header DEBUG_N to pin 11 of the xSYS header TDO to pin 13 of the xSYS header
Stdout can be directed to JTAG, XLink or UART. JTAG disruptes realtime execution. The UART interface executes at a rate of 2MB/s
TDO from XMOS chip on this PCB
TDO from last XMOS chip in chain
A connected header or mini DIN will ground this net
XTAGin / xSYS header
XTAGout
Buffered TMS
Buffered TCK
Global ~RST

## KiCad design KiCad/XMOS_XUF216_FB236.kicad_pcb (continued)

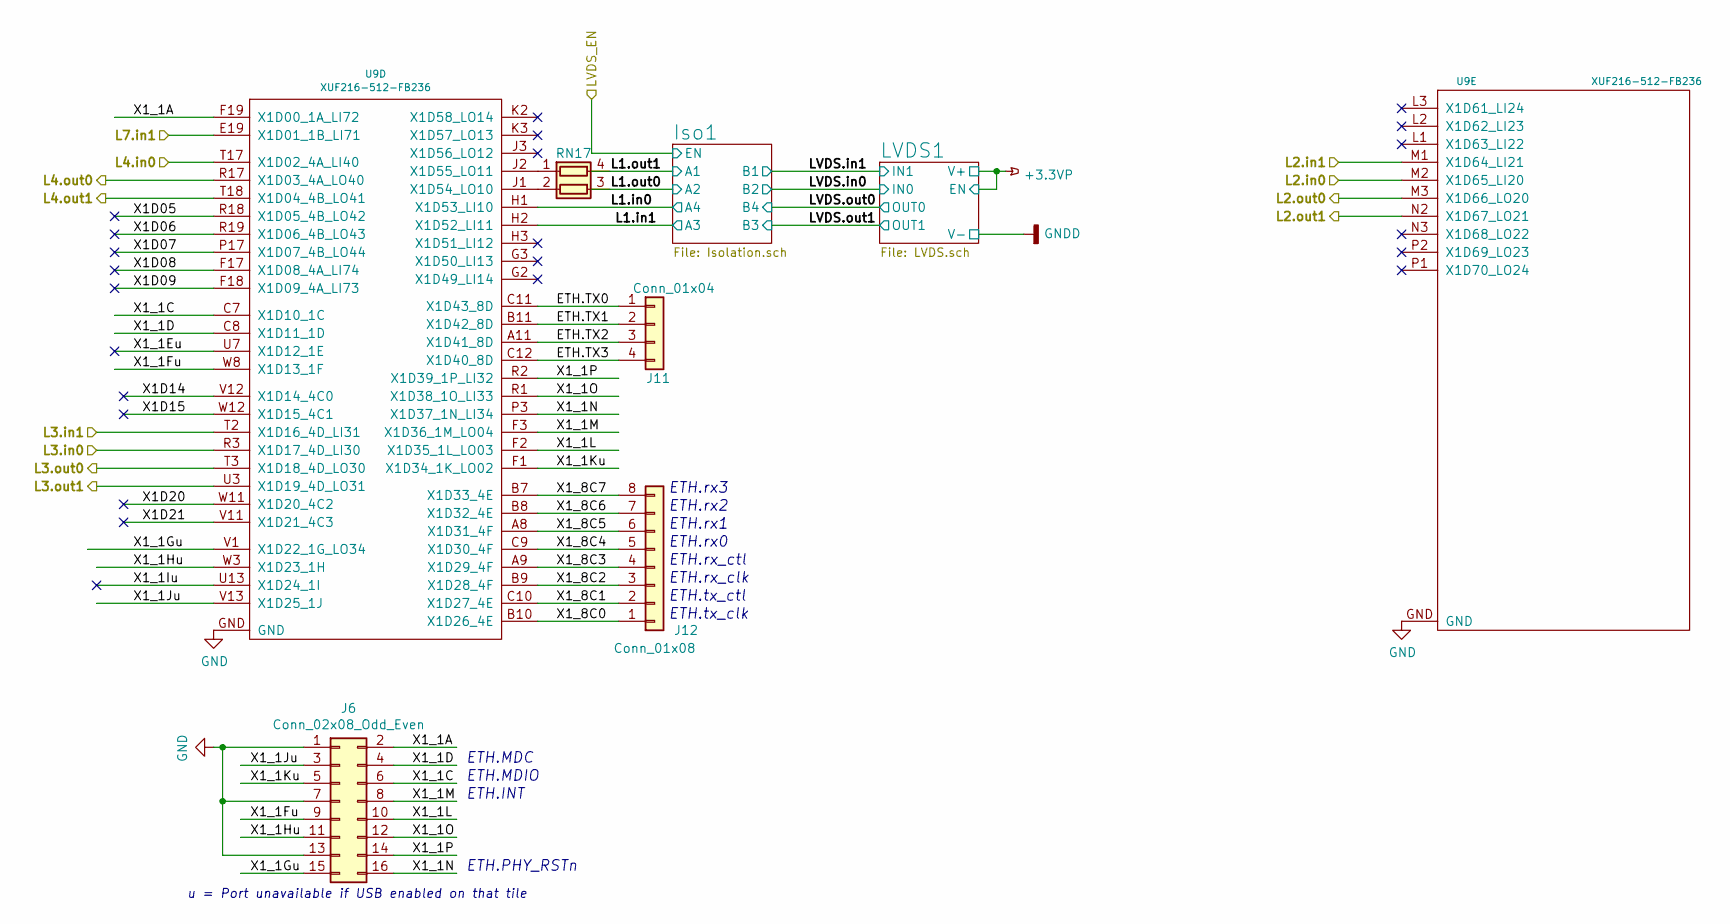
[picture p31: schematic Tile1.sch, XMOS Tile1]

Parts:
J6: Conn_02x08_Odd_Even; PinSocket_2x08_P2.54mm_Vertical
J11: Conn_01x04; PinSocket_1x04_P2.54mm_Vertical
J12: Conn_01x08; PinSocket_1x08_P2.54mm_Vertical
RN17: R_Pack02; R_Array_Convex_2x0402
U9: XUF216-512-FB236; BGA_236

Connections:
/L2.in0: U9.M2 (X1D65_LI20); also elsewhere on the board
/L2.in1: U9.M1 (X1D64_LI21); also elsewhere on the board
/L3.in0: U9.R3 (X1D17_4D_LI30); also elsewhere on the board
/L3.in1: U9.T2 (X1D16_4D_LI31); also elsewhere on the board
/L4.in0: U9.T17 (X1D02_4A_LI40); also elsewhere on the board
/L4.out0: U9.R17 (X1D03_4A_LO40); also elsewhere on the board
/L4.out1: U9.T18 (X1D04_4B_LO41); also elsewhere on the board
/L7.in1: U9.E19 (X1D01_1B_LI71); also elsewhere on the board
/Tile1/ETH.TX0: J11.1, U9.C11 (X1D43_8D)
/Tile1/ETH.TX1: J11.2, U9.B11 (X1D42_8D)
/Tile1/ETH.TX2: J11.3, U9.A11 (X1D41_8D)
/Tile1/ETH.TX3: J11.4, U9.C12 (X1D40_8D)
/Tile1/L1.in0: U9.H1 (X1D53_LI10); also elsewhere on the board
/Tile1/L1.in1: U9.H2 (X1D52_LI11); also elsewhere on the board
/Tile1/L1.out0: RN17.3 (R2.2); also elsewhere on the board
/Tile1/L1.out1: RN17.4 (R1.2); also elsewhere on the board
/Tile1/L2.out0: U9.M3 (X1D66_LO20); also elsewhere on the board
/Tile1/L2.out1: U9.N2 (X1D67_LO21); also elsewhere on the board
/Tile1/L3.out0: U9.T3 (X1D18_4D_LO30); also elsewhere on the board
/Tile1/L3.out1: U9.U3 (X1D19_4D_LO31); also elsewhere on the board
/Tile1/X1D05: U9.R18 (X1D05_4B_LO42)
/Tile1/X1D06: U9.R19 (X1D06_4B_LO43)
/Tile1/X1D07: U9.P17 (X1D07_4B_LO44)
/Tile1/X1D08: U9.F17 (X1D08_4A_LI74)
/Tile1/X1D09: U9.F18 (X1D09_4A_LI73)
/Tile1/X1D14: U9.V12 (X1D14_4C0)
/Tile1/X1D15: U9.W12 (X1D15_4C1)
/Tile1/X1D20: U9.W11 (X1D20_4C2)
/Tile1/X1D21: U9.V11 (X1D21_4C3)
/Tile1/X1_1A: J6.2, U9.F19 (X1D00_1A_LI72)
/Tile1/X1_1C: J6.6, U9.C7 (X1D10_1C)
/Tile1/X1_1D: J6.4, U9.C8 (X1D11_1D)
/Tile1/X1_1Eu: U9.U7 (X1D12_1E)
/Tile1/X1_1Fu: J6.9, U9.W8 (X1D13_1F)
/Tile1/X1_1Gu: J6.15, U9.V1 (X1D22_1G_LO34)
/Tile1/X1_1Hu: J6.11, U9.W3 (X1D23_1H)
/Tile1/X1_1Iu: U9.U13 (X1D24_1I)
/Tile1/X1_1Ju: J6.3, U9.V13 (X1D25_1J)
/Tile1/X1_1Ku: J6.5, U9.F1 (X1D34_1K_LO02)
/Tile1/X1_1L: J6.10, U9.F2 (X1D35_1L_LO03)
/Tile1/X1_1M: J6.8, U9.F3 (X1D36_1M_LO04)
/Tile1/X1_1N: J6.16, U9.P3 (X1D37_1N_LI34)
/Tile1/X1_1O: J6.12, U9.R1 (X1D38_1O_LI33)
/Tile1/X1_1P: J6.14, U9.R2 (X1D39_1P_LI32)
/Tile1/X1_8C0: J12.1, U9.B10 (X1D26_4E)
/Tile1/X1_8C1: J12.2, U9.C10 (X1D27_4E)
/Tile1/X1_8C2: J12.3, U9.B9 (X1D28_4F)
/Tile1/X1_8C3: J12.4, U9.A9 (X1D29_4F)
/Tile1/X1_8C4: J12.5, U9.C9 (X1D30_4F)
/Tile1/X1_8C5: J12.6, U9.A8 (X1D31_4F)
/Tile1/X1_8C6: J12.7, U9.B8 (X1D32_4E)
/Tile1/X1_8C7: J12.8, U9.B7 (X1D33_4E)
GND: J6.1, J6.7, J6.13, U9.GND; also elsewhere on the board
unnamed: RN17.1 (R1.1), U9.J2 (X1D55_LO11)
unnamed: RN17.2 (R2.1), U9.J1 (X1D54_LO10)

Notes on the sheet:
u = Port unavailable if USB enabled on that tile
ETH.MDIO
ETH.MDC
ETH.INT
ETH.PHY_RSTn
ETH.rx3
ETH.rx2
ETH.rx1
ETH.rx0
ETH.rx_ctl
ETH.rx_clk
ETH.tx_ctl
ETH.tx_clk

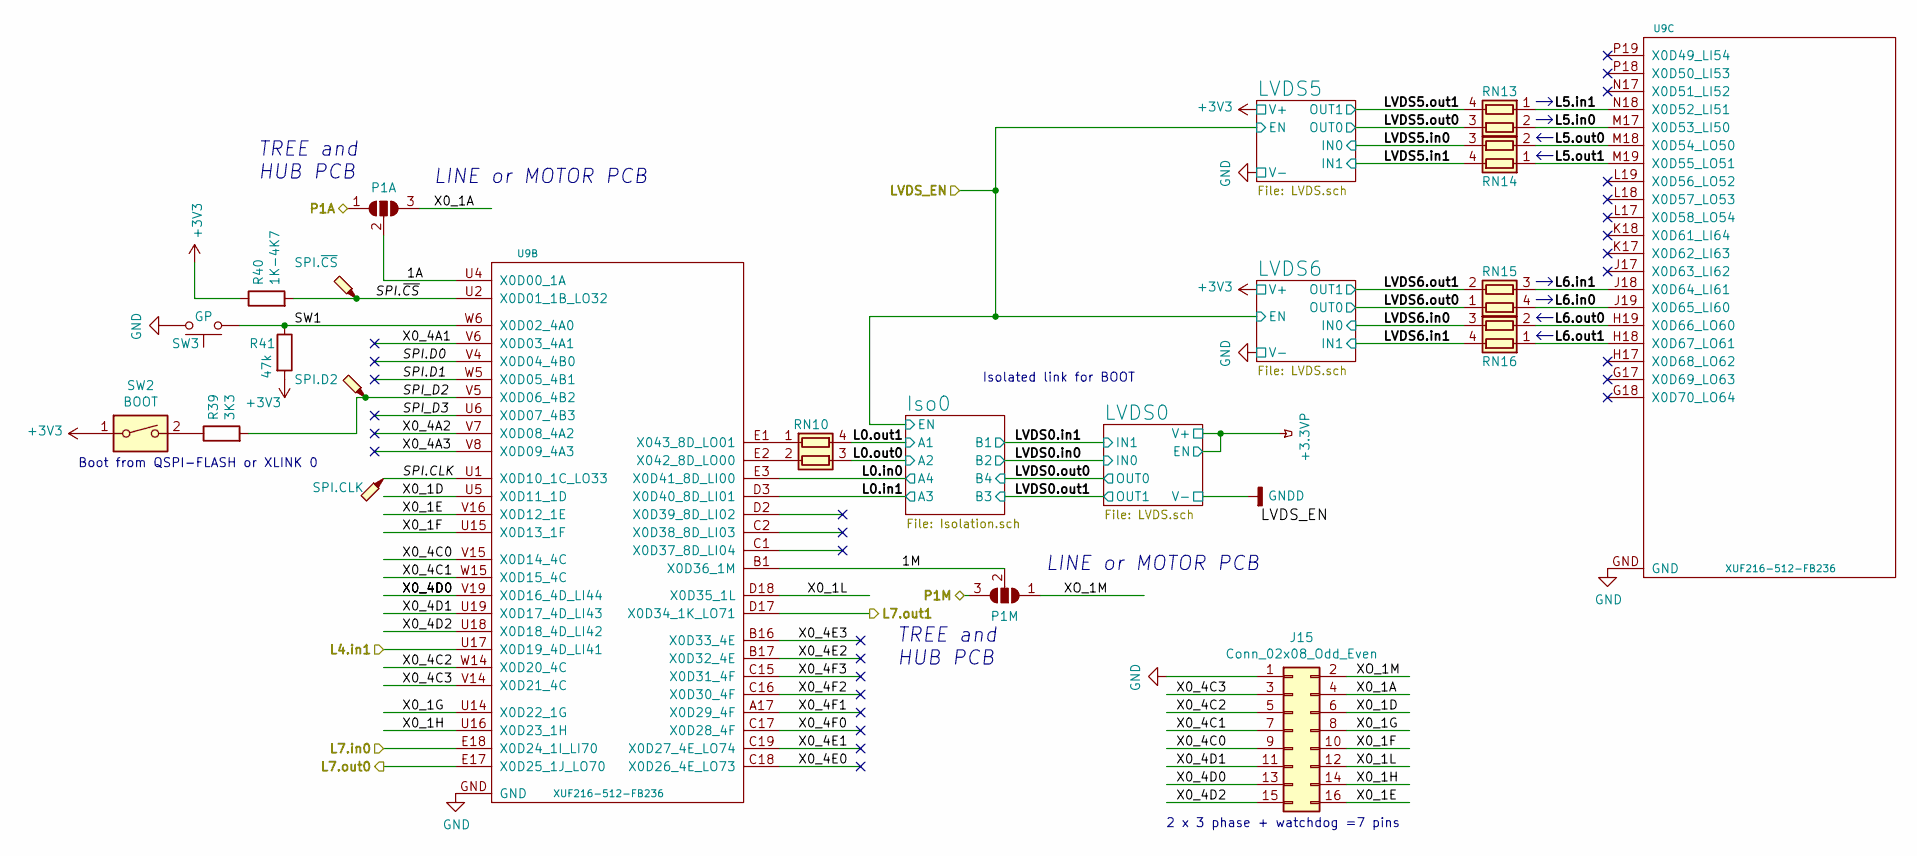
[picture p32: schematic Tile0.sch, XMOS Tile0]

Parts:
J15: Conn_02x08_Odd_Even; PinSocket_2x08_P2.54mm_Vertical
JP18: P1A; SolderJumper-3_P1.3mm_Open_RoundedPad1.0x1.5mm_NumberLabels
JP19: P1M; SolderJumper-3_P1.3mm_Open_RoundedPad1.0x1.5mm_NumberLabels
R39: 3K3; R_0603_1608Metric_Pad1.05x0.95mm_HandSolder
R40: 1K-4K7; R_0603_1608Metric_Pad1.05x0.95mm_HandSolder
R41: 47k; R_0603_1608Metric_Pad1.05x0.95mm_HandSolder
RN10, RN13, RN14, RN15, RN16: R_Pack02; R_Array_Convex_2x0402
SW2: BOOT; SW_DIP_SPSTx01_Slide_6.7x4.1mm_W6.73mm_P2.54mm_LowProfile_J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
SW3: GP; SW_SPST_B3U-1000P
TP20: SPI.~CS; TestPoint_Pad_0.6x0.6mm
TP21: SPI.D2; TestPoint_Pad_0.6x0.6mm
TP22: SPI.CLK; TestPoint_Pad_0.6x0.6mm
U9: XUF216-512-FB236; BGA_236

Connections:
/L4.in1: U9.U17 (X0D19_4D_LI41); also elsewhere on the board
/L7.in0: U9.E18 (X0D24_1I_LI70); also elsewhere on the board
/L7.out0: U9.E17 (X0D25_1J_LO70); also elsewhere on the board
/L7.out1: U9.D17 (X0D34_1K_LO71); also elsewhere on the board
/Tile0/1A: JP18.2 (C), U9.U4 (X0D00_1A)
/Tile0/1M: JP19.2 (C), U9.B1 (X0D36_1M)
/Tile0/L0.in0: U9.E3 (X0D41_8D_LI00); also elsewhere on the board
/Tile0/L0.in1: U9.D3 (X0D40_8D_LI01); also elsewhere on the board
/Tile0/L0.out0: RN10.3 (R2.2); also elsewhere on the board
/Tile0/L0.out1: RN10.4 (R1.2); also elsewhere on the board
/Tile0/L5.in0: RN13.2 (R2.1), U9.M17 (X0D53_LI50)
/Tile0/L5.in1: RN13.1 (R1.1), U9.N18 (X0D52_LI51)
/Tile0/L5.out0: RN14.2 (R2.1), U9.M18 (X0D54_LO50)
/Tile0/L5.out1: RN14.1 (R1.1), U9.M19 (X0D55_LO51)
/Tile0/L6.in0: RN15.4 (R1.2), U9.J19 (X0D65_LI60)
/Tile0/L6.in1: RN15.3 (R2.2), U9.J18 (X0D64_LI61)
/Tile0/L6.out0: RN16.2 (R2.1), U9.H19 (X0D66_LO60)
/Tile0/L6.out1: RN16.1 (R1.1), U9.H18 (X0D67_LO61)
/Tile0/LVDS5.in0: RN14.3 (R2.2); also elsewhere on the board
/Tile0/LVDS5.in1: RN14.4 (R1.2); also elsewhere on the board
/Tile0/LVDS5.out0: RN13.3 (R2.2); also elsewhere on the board
/Tile0/LVDS5.out1: RN13.4 (R1.2); also elsewhere on the board
/Tile0/LVDS6.in0: RN16.3 (R2.2); also elsewhere on the board
/Tile0/LVDS6.in1: RN16.4 (R1.2); also elsewhere on the board
/Tile0/LVDS6.out0: RN15.1 (R1.1); also elsewhere on the board
/Tile0/LVDS6.out1: RN15.2 (R2.1); also elsewhere on the board
/Tile0/SPI.CLK: TP22.1, U9.U1 (X0D10_1C_LO33)
/Tile0/SPI.D0: U9.V4 (X0D04_4B0)
/Tile0/SPI.D1: U9.W5 (X0D05_4B1)
/Tile0/SPI.~CS: R40.2, TP20.1, U9.U2 (X0D01_1B_LO32)
/Tile0/SPI_D2: R39.2, TP21.1, U9.V5 (X0D06_4B2)
/Tile0/SPI_D3: U9.U6 (X0D07_4B3)
/Tile0/SW1: R41.1, SW3.1, U9.W6 (X0D02_4A0)
/Tile0/X0_1A: J15.4, JP18.3 (B)
/Tile0/X0_1D: J15.6, U9.U5 (X0D11_1D)
/Tile0/X0_1E: J15.16, U9.V16 (X0D12_1E)
/Tile0/X0_1F: J15.10, U9.U15 (X0D13_1F)
/Tile0/X0_1G: J15.8, U9.U14 (X0D22_1G)
/Tile0/X0_1H: J15.14, U9.U16 (X0D23_1H)
/Tile0/X0_1L: J15.12, U9.D18 (X0D35_1L)
/Tile0/X0_4A1: U9.V6 (X0D03_4A1)
/Tile0/X0_4A2: U9.V7 (X0D08_4A2)
/Tile0/X0_4A3: U9.V8 (X0D09_4A3)
/Tile0/X0_4C0: J15.9, U9.V15 (X0D14_4C)
/Tile0/X0_4C1: J15.7, U9.W15 (X0D15_4C)
/Tile0/X0_4C2: J15.5, U9.W14 (X0D20_4C)
/Tile0/X0_4C3: J15.3, U9.V14 (X0D21_4C)
/Tile0/X0_4D0: J15.13, U9.V19 (X0D16_4D_LI44)
/Tile0/X0_4D1: J15.11, U9.U19 (X0D17_4D_LI43)
/Tile0/X0_4D2: J15.15, U9.U18 (X0D18_4D_LI42)
/Tile0/X0_4E0: U9.C18 (X0D26_4E_LO73)
/Tile0/X0_4E1: U9.C19 (X0D27_4E_LO74)
/Tile0/X0_4E2: U9.B17 (X0D32_4E)
/Tile0/X0_4E3: U9.B16 (X0D33_4E)
/Tile0/X0_4F0: U9.C17 (X0D28_4F)
/Tile0/X0_4F1: U9.A17 (X0D29_4F)
/Tile0/X0_4F2: U9.C16 (X0D30_4F)
/Tile0/X0_4F3: U9.C15 (X0D31_4F)
/Tile0/XO_1M: J15.2, JP19.1 (A)
/UART.RX: JP18.1 (A); also elsewhere on the board
/UART.TX: JP19.3 (B); also elsewhere on the board
GND: J15.1, SW3.2, U9.GND; also elsewhere on the board
unnamed: R39.1, SW2.2
unnamed: RN10.1 (R1.1), U9.E1 (X043_8D_LO01)
unnamed: RN10.2 (R2.1), U9.E2 (X042_8D_LO00)

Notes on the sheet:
2 x 3 phase + watchdog =7 pins
Boot from QSPI-FLASH or XLINK 0
Isolated link for BOOT
TREE and HUB PCB
LINE or MOTOR PCB

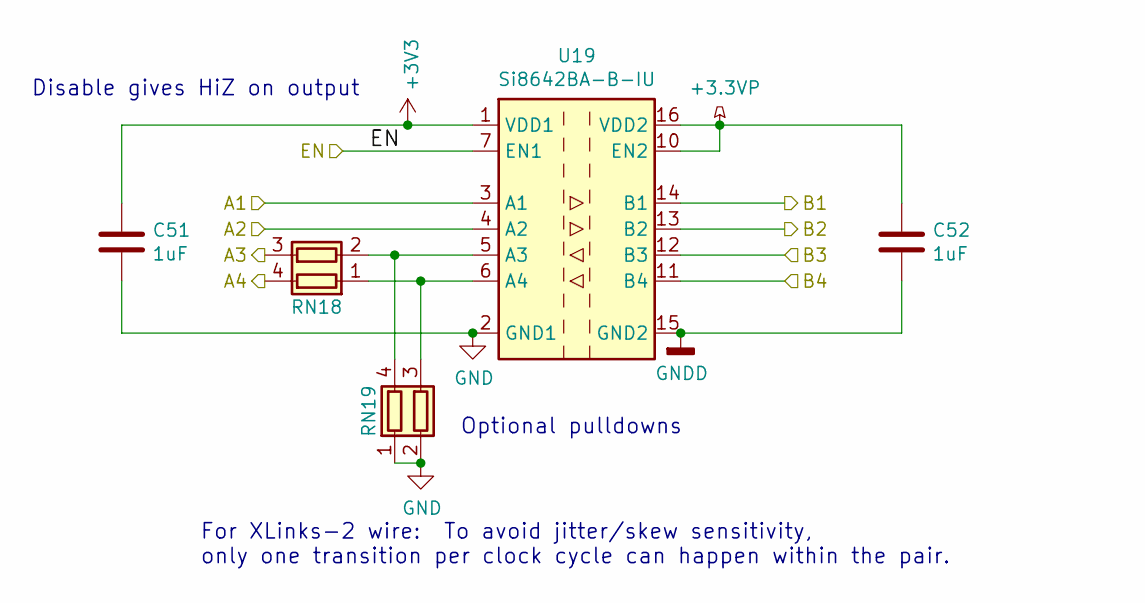
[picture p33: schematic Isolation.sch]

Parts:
C51, C52: 1uF; C_0603_1608Metric_Pad1.05x0.95mm_HandSolder
RN18, RN19: R_Pack02; R_Array_Convex_2x0402
U19: Si8642BA-B-IU; QSOP-16_3.9x4.9mm_P0.635mm

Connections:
+3.3VP: C52.1, U19.10 (EN2), U19.16 (VDD2); also elsewhere on the board
/LVDS_EN: U19.7 (EN1); also elsewhere on the board
/Tile0/L0.in0: RN18.4 (R1.2); also elsewhere on the board
/Tile0/L0.in1: RN18.3 (R2.2); also elsewhere on the board
/Tile0/L0.out0: U19.4 (A2); also elsewhere on the board
/Tile0/L0.out1: U19.3 (A1); also elsewhere on the board
/Tile0/LVDS0.in0: U19.13 (B2); also elsewhere on the board
/Tile0/LVDS0.in1: U19.14 (B1); also elsewhere on the board
/Tile0/LVDS0.out0: U19.11 (B4); also elsewhere on the board
/Tile0/LVDS0.out1: U19.12 (B3); also elsewhere on the board
GND: C51.2, RN19.1 (R1.1), RN19.2 (R2.1), U19.2 (GND1), U19.8 (GND1); also elsewhere on the board
GNDD: C52.2, U19.9 (GND2), U19.15 (GND2); also elsewhere on the board
unnamed: RN18.1 (R1.1), RN19.3 (R2.2), U19.6 (A4)
unnamed: RN18.2 (R2.1), RN19.4 (R1.2), U19.5 (A3)

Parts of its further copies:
C44, C45: 1uF; C_0603_1608Metric_Pad1.05x0.95mm_HandSolder
RN11, RN12: R_Pack02; R_Array_Convex_2x0402
U13: Si8642BA-B-IU; QSOP-16_3.9x4.9mm_P0.635mm

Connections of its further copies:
+3.3VP: C45.1, U13.10 (EN2), U13.16 (VDD2); also elsewhere on the board
/LVDS_EN: U13.7 (EN1); also elsewhere on the board
/Tile1/L1.in0: RN11.4 (R1.2); also elsewhere on the board
/Tile1/L1.in1: RN11.3 (R2.2); also elsewhere on the board
/Tile1/L1.out0: U13.4 (A2); also elsewhere on the board
/Tile1/L1.out1: U13.3 (A1); also elsewhere on the board
/Tile1/LVDS.in0: U13.13 (B2); also elsewhere on the board
/Tile1/LVDS.in1: U13.14 (B1); also elsewhere on the board
/Tile1/LVDS.out0: U13.11 (B4); also elsewhere on the board
/Tile1/LVDS.out1: U13.12 (B3); also elsewhere on the board
GND: C44.2, RN12.1 (R1.1), RN12.2 (R2.1), U13.2 (GND1), U13.8 (GND1); also elsewhere on the board
GNDD: C45.2, U13.9 (GND2), U13.15 (GND2); also elsewhere on the board
unnamed: RN11.1 (R1.1), RN12.3 (R2.2), U13.6 (A4)
unnamed: RN11.2 (R2.1), RN12.4 (R1.2), U13.5 (A3)

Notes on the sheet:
For XLinks-2 wire: To avoid jitter/skew sensitivity, only one transition per clock cycle can happen within the pair.
Disable gives HiZ on output
Optional pulldowns

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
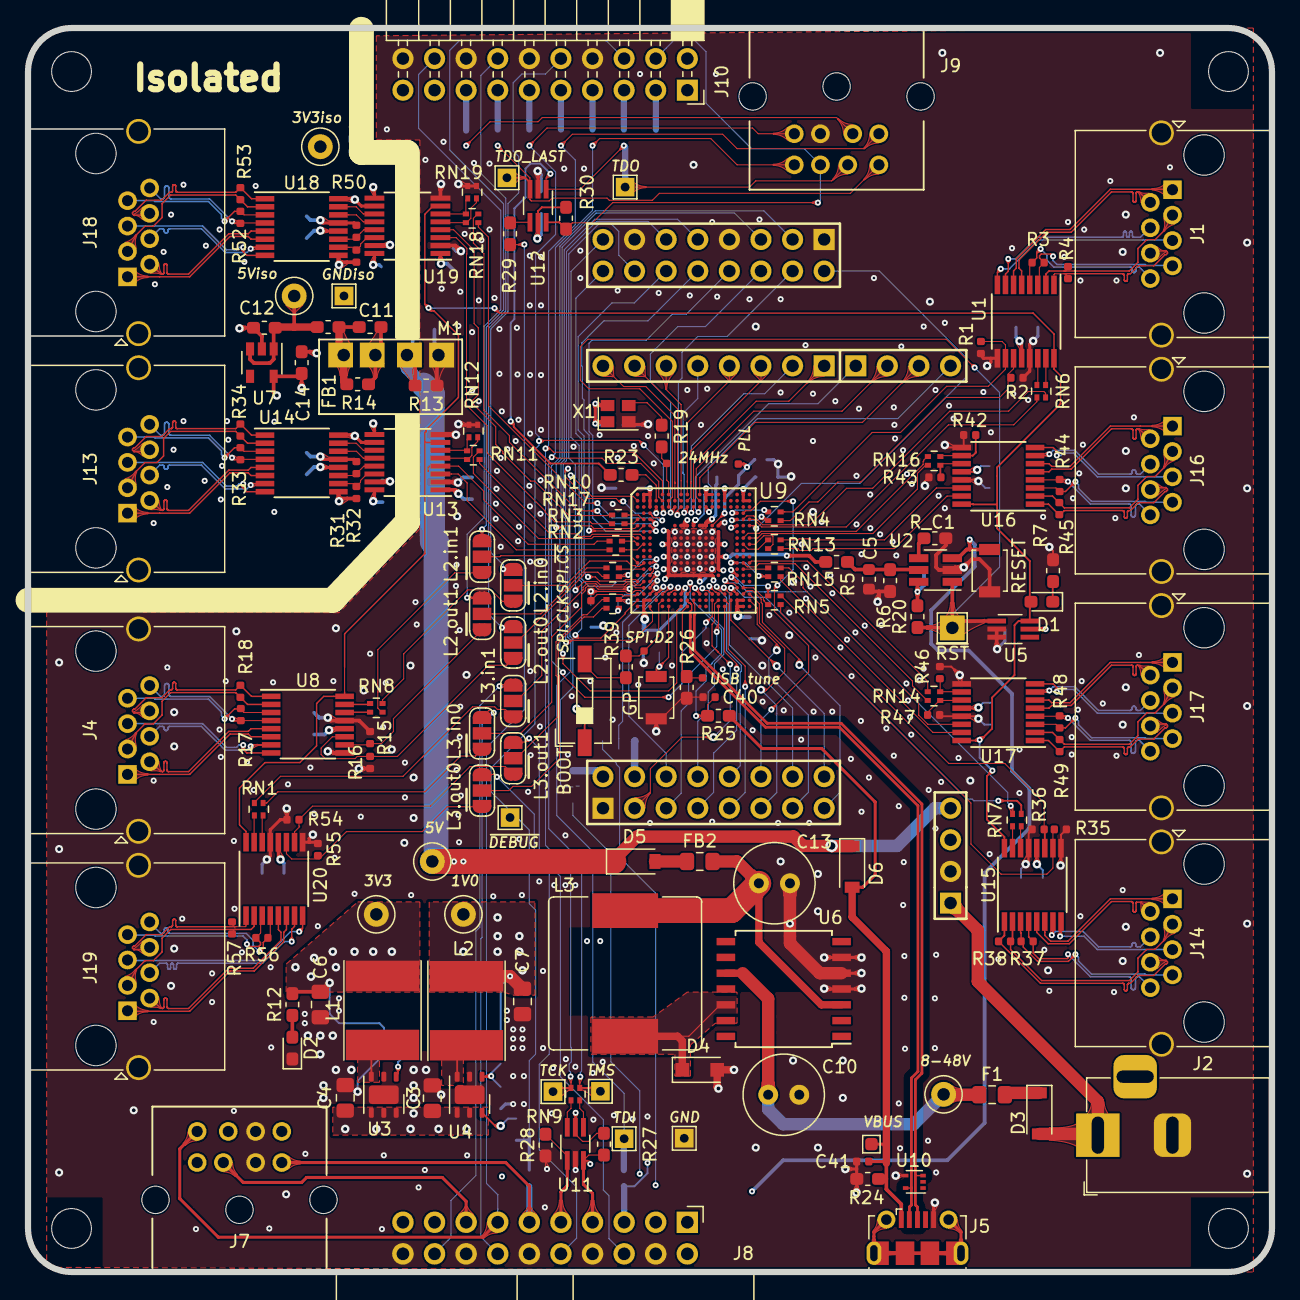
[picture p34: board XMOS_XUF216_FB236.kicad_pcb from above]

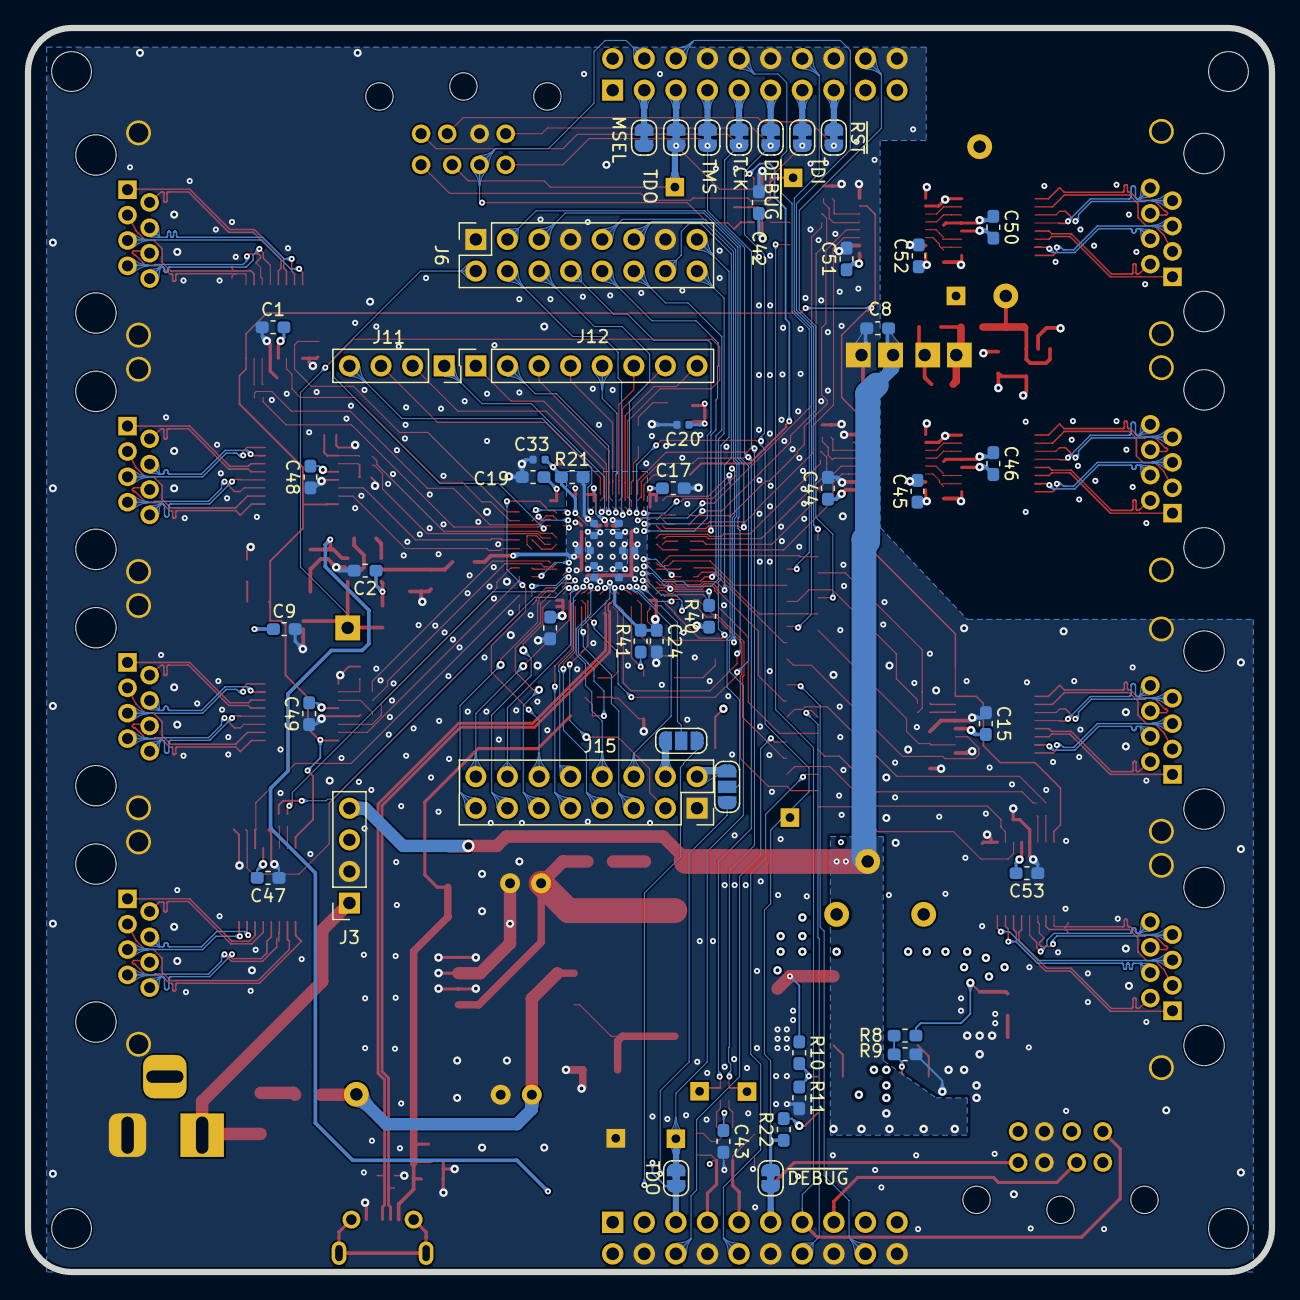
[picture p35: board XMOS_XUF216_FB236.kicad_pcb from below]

Board: 4 copper layers, 100.0 x 100.0 mm, 219 parts (53 on the bottom side), 258 nets.

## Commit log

2018-12-29 Added a set of termination resistors
2018-12-29 Changed plotmode of Board.pdf
2018-12-29 Updated Fab Layer in board
2018-12-30 Added reference pdf and some schematic fixes.
2018-12-30 Added powerpoints
2019-01-01 Create XDK Schematics.pdf
2019-01-01 Added Mini DIN8 connectors and TREE/LINE choice
2019-01-01 Schematic refactoring
2019-01-03 Added new board renderings and small schematic adjustment
2019-01-03 Updated board and renders
2019-01-03 Minor changes to the PCB
2019-01-04 Added M3 standoffs
2019-01-05 Added KiCAD files
    [Isolation.sch, LVDS.sch, Tile0.sch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]
2019-01-06 Added impedance calc, and rerouted USB
    [LVDS.sch, XMOS_USB.sch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]
2019-01-08 Many small fixes
    [Isolation.sch, LVDS.sch, Tile0.sch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]
2019-01-08 Updated VRML and schematic
    [Isolation.sch, LVDS.sch, Tile0.sch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]
2020-06-17 Update
    Updated to KiCad 5.1.6 and changed the power sheet etc.
    [Isolation.sch, LVDS.sch, Tile0.sch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]
